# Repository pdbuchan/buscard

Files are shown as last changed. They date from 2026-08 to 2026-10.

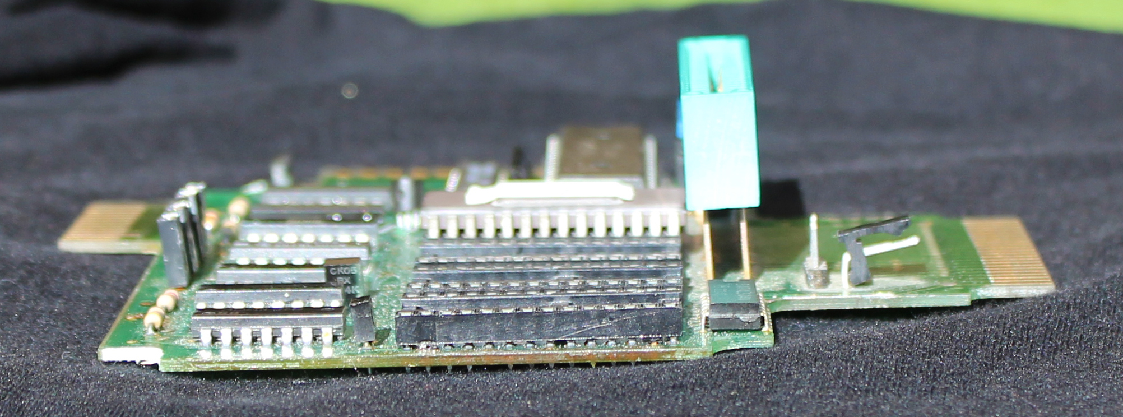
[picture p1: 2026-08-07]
docs/assets/images/side_view03.jpg

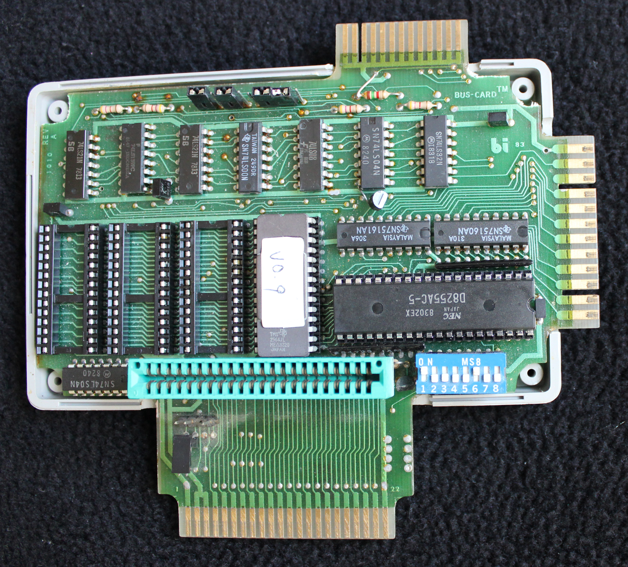
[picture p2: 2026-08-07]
docs/assets/images/top_with_bottom_cover1.jpg

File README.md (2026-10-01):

# BusCard Project

The illustrated project description is available on the [BusCard GitHub Pages website](https://pdbuchan.github.io/buscard/).

This repository documents information on the BusCard, an IEEE-488 and parallel printer interface for the Commodore 64. The BusCard, and subsequent BusCard II, were manufactured by Batteries Included Ltd. of Toronto, Canada. On my BusCard, the circuit board is labeled "Rev A" and "1983". I used it to provide IEEE-488 functionality to my Commodore 64 in order to use a 4040 disk drive and 8023P printer. It also provides BASIC 4.0 and comes with an assembler and disassembler.

Unlike the BusCard II, the BusCard does not contain any proprietary integrated circuits. As a result, I was able to successfully reverse-engineer it and produce an exact working duplicate. I used EAGLE CAD software for the schematic and circuit board design. All information required to produce it is provided. If you would like to build it, you can send the GERBER files provided here to the manufacturer of your choice. You would only need EAGLE if you wish to change the board layout or circuit.

## License

All of my photographs and EAGLE files are released under [Creative Commons License CC BY-SA](https://creativecommons.org/licenses/by-sa/4.0/). The original BusCard, EPROM content, and user manual are copyright Batteries Included Ltd.

## Repository layout

```text
buscard/
├── README.md
└── docs/
    ├── README.md
    ├── index.html
    ├── .nojekyll
    └── assets/
        ├── buscard.css
        ├── buscard_rev_a_manual.pdf
        ├── schematic.pdf
        ├── cam/
        │   ├── README.md
        │   └── elecrow-gerb274x.cam
        ├── datasheets/
        │   ├── README.md
        │   ├── datasheets.html
        │   ├── 1N4148.pdf
        │   ├── 2N3904.pdf
        │   ├── 2N4401.pdf
        │   ├── 74LS00N.pdf
        │   ├── 74LS04N.pdf
        │   ├── 74LS08N.pdf
        │   ├── 74LS139N.pdf
        │   ├── 74LS21N.pdf
        │   ├── 74LS32N.pdf
        │   ├── 75160B.pdf
        │   ├── 75161B.pdf
        │   ├── 8255AC-5.pdf
        │   ├── 82C55A.pdf
        │   ├── 8-SPST-DIP-Switch.pdf
        │   ├── CK05BX104K.pdf
        │   ├── clip_cable.pdf
        │   ├── clip_receptacle.pdf
        │   ├── female-edge-connector.pdf
        │   ├── micro_clip.pdf
        │   ├── resistor-network.pdf
        │   ├── resistors.pdf
        │   ├── shunt.pdf
        │   └── TMS2564.pdf
        ├── drawings/
        │   ├── README.md
        │   ├── buscard_dimensions.pdf
        │   ├── buscard_dimensions.vsdx
        │   ├── buscard_expansion_port.pdf
        │   ├── buscard_expansion_port.vsdx
        │   ├── buscard_IEEE-488_port.pdf
        │   ├── buscard_IEEE-488_port.vsdx
        │   ├── buscard_parallel_port.pdf
        │   ├── buscard_parallel_port.vsdx
        │   ├── buscard_parts_layout.pdf
        │   ├── buscard_parts_layout.vsdx
        │   ├── buscard_schematic.pdf
        │   ├── new_buscard_dimensions.pdf
        │   └── new_buscard_dimensions.vsdx
        ├── eagle/
        │   ├── README.md
        │   ├── buscard.brd
        │   └── buscard.sch
        ├── eprom/
        │   ├── README.md
        │   ├── buscardv0.9-tms2564.html
        │   ├── buscard_u1_rom_discussion.html
        │   ├── additional-sockets-u13-u14-u15.html
        │   ├── burning_TMS2564_EPROM.docx
        │   ├── burning_TMS2564_EPROM.pdf
        │   ├── buscard_u1_6502_annotated_listing.txt
        │   ├── buscard_u1_rom_discussion.md
        │   ├── additional-sockets-u13-u14-u15.md
        │   └── buscardv0.9-tms2564.bin
        ├── gerber/
        │   ├── README.md
        │   ├── gerber.html
        │   ├── buscard.GBL
        │   ├── buscard.GBO
        │   ├── buscard.GBS
        │   ├── buscard.GML
        │   ├── buscard.GTL
        │   ├── buscard.GTO
        │   ├── buscard.GTS
        │   ├── buscard.TXT
        │   ├── PLEASE_CHAMFER_CARD_EDGES.jpg
        │   └── PLEASE_CONTACT_ME_ABOUT_GOLD_FINGERS.txt
        ├── images/
        │   ├── README.md
        │   ├── orig_gallery.html
        │   ├── new_gallery.html
        │   ├── bottom_cover_inside.jpg
        │   ├── bottom_cover_inside_thumb.jpg
        │   ├── bottom_cover_underside.jpg
        │   ├── bottom_cover_underside_thumb.jpg
        │   ├── bottom.jpg
        │   ├── bottom_of_board_backlit.jpg
        │   ├── bottom_of_board_backlit_thumb.jpg
        │   ├── bottom_thumb.jpg
        │   ├── clips.jpg
        │   ├── clips_thumb.jpg
        │   ├── diodes.jpg
        │   ├── diodes-switch_foil_backlit_top.jpg
        │   ├── diodes-switch_foil_backlit_top_thumb.jpg
        │   ├── diodes-switch_foil_top.jpg
        │   ├── diodes-switch_foil_top_thumb.jpg
        │   ├── diodes_thumb.jpg
        │   ├── expansion_port_backlit1.jpg
        │   ├── expansion_port_backlit1_thumb.jpg
        │   ├── expansion_port_backlit2.jpg
        │   ├── expansion_port_backlit2_thumb.jpg
        │   ├── new_bottom.jpg
        │   ├── new_bottom_thumb.jpg
        │   ├── new_top1.jpg
        │   ├── new_top1_thumb.jpg
        │   ├── new_top2.jpg
        │   ├── new_top2_thumb.jpg
        │   ├── new_top_no_chips1.jpg
        │   ├── new_top_no_chips1_thumb.jpg
        │   ├── new_top_no_chips2.jpg
        │   ├── new_top_no_chips2_thumb.jpg
        │   ├── not_plugged_in.jpg
        │   ├── not_plugged_in_thumb.jpg
        │   ├── photo_buscard_board_bottom_r0.jpg
        │   ├── photo_buscard_board_top_r0.jpg
        │   ├── plugged_in.jpg
        │   ├── plugged_in_thumb.jpg
        │   ├── side_view01.jpg
        │   ├── side_view01_thumb.jpg
        │   ├── side_view02.jpg
        │   ├── side_view02_thumb.jpg
        │   ├── side_view03.jpg
        │   ├── side_view03_thumb.jpg
        │   ├── side_view04.jpg
        │   ├── side_view04_thumb.jpg
        │   ├── side_view05.jpg
        │   ├── side_view05_thumb.jpg
        │   ├── side_view06.jpg
        │   ├── side_view06_thumb.jpg
        │   ├── side_view07.jpg
        │   ├── side_view07_thumb.jpg
        │   ├── side_view08.jpg
        │   ├── side_view08_thumb.jpg
        │   ├── side_view09.jpg
        │   ├── side_view09_thumb.jpg
        │   ├── side_view10.jpg
        │   ├── side_view10_thumb.jpg
        │   ├── side_view11.jpg
        │   ├── side_view11_thumb.jpg
        │   ├── side_view12.jpg
        │   ├── side_view12_thumb.jpg
        │   ├── side_view13.jpg
        │   ├── side_view13_thumb.jpg
        │   ├── top_cover_inside.jpg
        │   ├── top_cover_inside_thumb.jpg
        │   ├── top_foil1.jpg
        │   ├── top_foil1_thumb.jpg
        │   ├── top_no_covers1.jpg
        │   ├── top_no_covers1_thumb.jpg
        │   ├── top_no_covers2.jpg
        │   ├── top_no_covers2_thumb.jpg
        │   ├── top_of_board_backlit.jpg
        │   ├── top_of_board_backlit_thumb.jpg
        │   ├── top_with_bottom_cover1.jpg
        │   ├── top_with_bottom_cover1_thumb.jpg
        │   ├── top_with_bottom_cover2.jpg
        │   ├── top_with_bottom_cover2_thumb.jpg
        │   ├── top_with_cover1.jpg
        │   ├── top_with_cover1_thumb.jpg
        │   ├── top_with_cover2.jpg
        │   └── top_with_cover2_thumb.jpg
        ├── libraries/
        │   ├── README.md
        │   ├── libraries.html
        │   ├── 1N4148.lbr
        │   ├── 2564.lbr
        │   ├── 2N3904_and_2N4401.lbr
        │   ├── 74LS00N.lbr
        │   ├── 74LS04N.lbr
        │   ├── 74LS08N.lbr
        │   ├── 74LS139N.lbr
        │   ├── 74LS21N.lbr
        │   ├── 74LS32N.lbr
        │   ├── 75160AN.lbr
        │   ├── 75161AN.lbr
        │   ├── 8255AC-5.lbr
        │   ├── capacitor-CK05BX104K.lbr
        │   ├── clip-header-MTA02-100.lbr
        │   ├── commodore-card-edges.lbr
        │   ├── dip-switch-DS08.lbr
        │   ├── female-44-pin-edge-connector.lbr
        │   ├── frame.lbr
        │   ├── jumper-header-3.lbr
        │   ├── mystery_plug-MTA04-100.lbr
        │   ├── resistor.lbr
        │   └── resistor-network-sil-G09R.lbr
        └── parts/
            ├── README.md
            ├── new_buscard_bom.xlsx
            └── orig_buscard_parts.xlsx
```

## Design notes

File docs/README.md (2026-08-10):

# Website HTML files and assets

This directory is the GitHub Pages document root.

| HTML File | Description |
|---|---|
| `index.html` | The project main webpage |
| `assets/images/orig_gallery.html` | A gallery webpage for the original BusCard |
| `assets/images/new_gallery.html` | A gallery webpage for my reverse-engineered BusCard |
| `assets/gerber/gerber.html` | A webpage for the GERBER files to be sent to a PCB manufacturer |
| `assets/datasheets/datasheets.html` | A webpage listing various component datasheets |
| `assets/libraries/libraries.html` | A webpage listing my custom EAGLE libraries for various components |
| `.nojekyll` | Tells GitHub Pages to serve the files without Jekyll processing |

| File | Description |
|---|---|
| `assets/buscard.css` | Shared stylesheet for BusCard project |
| `assets/buscard_rev_a_manual.pdf` | Scan of the BusCard manual with errata incorporated |
| `assets/schematic.pdf` | The reverse-engineered BusCard schematic, rendered by EAGLE |

| Directory | Description |
|---|---|
| `assets/cam/` | The EAGLE CAM file for generating the GERBER files |
| `assets/datasheets/` | Datasheets for the various BusCard components |
| `assets/drawings/` | My original hand-drawn schematic, and other drawings I prepared |
| `assets/eagle/` | EAGLE board and schematic files |
| `assets/eprom/` | TMS-2564 EPROM binary image, as well as instructions for burning copies using the Promenade EPROM burner |
| `assets/gerber/` | The GERBER files to be sent to a PCB manufacturer |
| `assets/images/` | Photographs of the original and reverse-engineered BusCards |
| `assets/libraries/` | My custom EAGLE libraries for various components |
| `assets/parts/` | Parts lists for original and new BusCards as Microsoft Excel spreadsheets |

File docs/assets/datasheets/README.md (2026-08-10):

# Datasheets for various components of the BusCard

| File | Description |
|---|---|
| `1N4148.pdf` | Small Signal Diode, 200 mA, 100 V |
| `2N3904.pdf` | NPN Transistor, 200 mA, 40 V |
| `2N4401.pdf` | NPN Transistor, 600 mA, 40 V |
| `74LS00N.pdf` | Quadruple 2-Input Positive-NAND Gates |
| `74LS04N.pdf` | Hex Inverting Gates |
| `74LS08N.pdf` | Quadruple 2-Input Positive-AND Gates |
| `74LS139N.pdf` | Dual 1-of-4 Decoder/Demultiplexer |
| `74LS21N.pdf` | Dual 4-Input Positive-AND Gates |
| `74LS32N.pdf` | Quadruple 2-Input Positive-OR Gates |
| `75160B.pdf` | IEEE-488 GPIB Octal Bus Transceiver |
| `75161B.pdf` | IEEE-488 GPIB Octal Bus-Management and Data-Transfer Transceiver |
| `8255AC-5.pdf` | Programmable Peripheral Interface, 40-Pin, 4 MHz |
| `82C55A.pdf` | Programmable Peripheral Interface, 40-Pin, 4 MHz |
| `8-SPST-DIP-Switch.pdf` | 8 SPST DIP Switch, Raised Slide |
| `CK05BX104K.pdf` | Ceramic Capacitor, 0.1 uF, 50 V, Radial, 10% tolerance |
| `clip_cable.pdf` | Ribbon cable |
| `clip_receptacle.pdf` | Receptacle for ribbon cable |
| `female-edge-connector.pdf` | Edge connector for accepting Commodore cartridges |
| `micro_clip.pdf` | Micro clip for ribbon cable |
| `resistor-network.pdf` | SIL Resistor Network, 4.67 kohm, 10 Pins, 9 Resistors, Bussed Arrangement |
| `resistors.pdf` | Resistor (general) |
| `shunt.pdf` | Shunts for jumpering pins on BusCard |
| `TMS2564.pdf` | 65,536-bit, Ultraviolet-Erasable, Electrically Programmable Read-Only Memory (EPROM) |

## File for GitHub Pages
| File | Description |
|---|---|
| `datasheets.html` | Webpage about datasheets for GitHub Pages |

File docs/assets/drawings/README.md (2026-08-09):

# My original hand-drawn schematic, and other drawings I produced

| File | Description |
|---|---|
| `buscard_dimensions.pdf` | Original BusCard printed circuit board dimensions as PDF |
| `buscard_dimensions.vsdx` | Original BusCard printed circuit board dimensions as Microsoft Visio drawing |
| `buscard_expansion_port.pdf` | BusCard expansion port dimensions as PDF |
| `buscard_expansion_port.vsdx` | BusCard expansion port dimensions as Microsoft Visio drawing |
| `buscard_IEEE-488_port.pdf` | IEEE-488 port pinout as PDF |
| `buscard_IEEE-488_port.vsdx` | IEEE-488 port pinout as Microsoft Visio drawing |
| `buscard_parallel_port.pdf` | BusCard parallel port pinout as PDF |
| `buscard_parallel_port.vsdx` | BusCard parallel port pinout as Microsoft Visio drawing |
| `buscard_parts_layout.pdf` | BusCard parts layout as PDF, referencing component IDs in `assets/parts/orig_buscard_parts.xlsx` |
| `buscard_parts_layout.vsdx` | BusCard parts layout referencing component IDs in `assets/parts/buscard_bom.xlsx and buscard_parts_list.txt` as Microsoft Visio drawing |
| `buscard_schematic.pdf` | My original hand-drawn schematic |
| `new_buscard_dimensions.pdf` | Reverse-engineered BusCard printed circuit board dimensions as PDF |
| `new_buscard_dimensions.vsdx` | Reverse-engineered BusCard printed circuit board dimensions as Microsoft Visio drawing |

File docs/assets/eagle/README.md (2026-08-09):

# EAGLE board and schematic files

| File | Description |
|---|---|
| `buscard.brd` | EAGLE printed circuit board file |
| `buscard.sch` | EAGLE schematic file |

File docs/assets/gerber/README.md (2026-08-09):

# GERBER files to send to PCB manufacturer

| File | Description |
|---|---|
| `buscard.GBL` | Bottom copper layer |
| `buscard.GBO` | Bottom overlay (silkscreen) |
| `buscard.GBS` | Bottom solder mask |
| `buscard.GML` | Mill layer |
| `buscard.GTL` | Top copper layer |
| `buscard.GTO` | Top overlay (silkscreen) |
| `buscard.GTS` | Top solder mask |
| `buscard.TXT` | Drill file |

At the time I had my boards manufactured, [Elecrow](https://www.elecrow.com/) told me to include a request for them to contact me regarding gold fingers.

| File | Description |
|---|---|
| `PLEASE_CHAMFER_CARD_EDGES.jpg` | Shows locations of PCB edges to be chamfered. |
| `PLEASE_CONTACT_ME_ABOUT_GOLD_FINGERS.txt` | Instruction to contact me regarding gold fingers. |

## File for GitHub Pages

| File | Description |
|---|---|
| `gerber.html` | HTML webpage for GitHub Pages regarding GERBER files |

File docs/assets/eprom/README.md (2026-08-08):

# BusCard (Revision A) TMS-2564 EPROM v0.9 (U1)

| File | Description |
|---|---|
| `buscardv0.9-tms2564.bin` | Binary image of BusCard EPROM |
| [`buscard_u1_rom_discussion.md`](buscard_u1_rom_discussion.md) | Discussion of BusCard TMP-2564 EPROM U1 Disassembly |
| `buscard_u1_6502_annotated_listing.txt` | BusCard TMP-2564 EPROM U1 Annotated Disassembly |
| [`additional-sockets-u13-u14-u15.md`](additional-sockets-u13-u14-u15.md) | Discussion on the U13, U14, and U15 EPROM Sockets |

## Instructions for Burning Copies of the EPROM

| File | Description |
|---|---|
| `burning_TMS2564_EPROM.docx` | Instructions for burning copies of the BusCard EPROM using the Promenade EPROM burner as Microsoft Word document |
| `burning_TMS2564_EPROM.pdf` | Instructions for burning copies of the BusCard EPROM using the Promenade EPROM burner as PDF |

## Files for GitHub Pages

| File | Description |
|---|---|
| `buscardv0.9-tms2564.html` | Webpage for BusCard TMP-2564 EPROM U1 |
| `buscard_u1_rom_discussion.html` | Discussion of BusCard TMP-2564 EPROM U1 Disassembly |
| `additional-sockets-u13-u14-u15.html` | Discussion on the U13, U14, and U15 EPROM Sockets |

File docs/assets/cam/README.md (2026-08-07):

# EAGLE CAM file for generating the GERBER files to be sent to manufacturer

I hired [Elecrow](https://www.elecrow.com/) to manufacture my boards.

`elecrow-gerb274x.cam`

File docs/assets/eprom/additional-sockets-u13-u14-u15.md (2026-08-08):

# Batteries Included BusCard U13, U14, and U15 EPROM Sockets
## Purpose and relationship to the U1 firmware

## Purpose of this document

The Batteries Included BusCard contains one normally populated TMS2564 EPROM,
U1, and three additional TMS2564 sockets, XU13, XU14, and XU15. On the BusCard
examined during this project, only U1 was populated. The purpose of the three
additional sockets is therefore not immediately obvious from the surviving
board alone.

Reverse engineering of U1, examination of the BusCard schematic, and comparison
with the current MAME BusCard hardware model now allow the hardware role of
U13-U15 to be described with fairly high confidence. Their **exact original ROM
contents remain unknown**, but their electrical function and likely intended
software role are much clearer.

The principal conclusion is:

> **U13, U14, and U15 form an optional three-bank ROM facility that can replace
> the normal C64 BASIC ROM in the `$A000-$BFFF` address range. Together they
> provide 24K of physical ROM storage, but only one 8K bank is visible to the
> 6510 at a time. The available evidence strongly indicates that this facility
> was intended for an optional BASIC-related ROM package, distinct from the
> smaller BASIC 4.0-style command extension already contained in U1.**

This distinction between the U1 command extension and the optional U13-U15 ROM
facility is important.

## What the U1 disassembly established

U1 is an 8192-byte TMS2564 EPROM, but it is not used as one simple contiguous
8K program. The BusCard maps different parts of U1 into different parts of the
C64 address space. The reconstructed organization is:

| Physical U1 offset | CPU address | Principal contents |
| --- | --- | --- |
| `$0000-$0BFF` | `$A000-$ABFF` | Machine-language monitor and low-level BusCard I/O drivers |
| `$0C00-$0FFF` | `$EC00-$EFFF` | Resident C64 KERNAL overlay and BusCard dispatch code |
| `$1000-$113B` | `$B000-$B13B` | BASIC extension installer/uninstaller and associated data |
| `$113C-$147A` | `$B13C-$B47A` | Zero fill |
| `$147B-$1FFF` | `$B47B-$BFFF` | Encoded relocatable BASIC command extension |

The resident ROM provides three public entry points:

| BASIC command | Address | Function |
| --- | ---: | --- |
| `SYS 61000` | `$EE48` | Install/enable the BusCard BASIC 4.0-style command extension |
| `SYS 61003` | `$EE4B` | Remove/disable the command extension |
| `SYS 61006` | `$EE4E` | Enter the BusCard machine-language monitor |

The important discovery is that `SYS 61000` does **not** enable U13, U14, or
U15. Instead, U1 contains an encoded relocation stream. The installer expands
this code into RAM below BASIC's current `MEMSIZ`, then hooks four standard
BASIC indirect vectors. On a stock C64 with `MEMSIZ=$A000`, the reconstructed
runtime extension occupies `$955B-$9FFF` and is 2725 bytes long.

The relocated image identifies itself as `BASIC 4.0` and adds fifteen
Commodore-style disk commands:

```
CONCAT   DOPEN    DCLOSE   RECORD    HEADER
COLLECT  BACKUP   COPY     APPEND    DSAVE
DLOAD    CATALOG  RENAME   SCRATCH   DIRECTORY
```

This means that the BusCard already supplies a useful BASIC 4.0-style disk
command environment using **U1 alone**. The optional sockets are therefore not
required merely to make `SYS 61000` work, and they would not simply contain
three more pieces of the U1 command wedge.

## What the schematic says about U13-U15

The schematic shows four TMS2564 devices associated with the BusCard ROM
system:

- U1, controlled by `PD/!PGM1`;
- U13, controlled by `PD/!PGM2`;
- U14, controlled by `PD/!PGM3`;
- U15, controlled by `PD/!PGM4`.

U13, U14, and U15 share the same address and data buses. Each is an 8K x 8
EPROM, so the three sockets provide 24K of physical storage.

The crucial difference is their chip-selection logic. Two outputs from the
Intel 8255 PPI, `PB0` and `PB1`, feed one half of U10, a 74LS139 two-to-four
line decoder. Three decoder outputs are wired to the three optional EPROMs:

| 8255 bank bits | 74LS139 output | Selected EPROM |
| --- | --- | --- |
| `PB1 PB0 = 00` | `Y0` / `PD/!PGM4` | U15 |
| `PB1 PB0 = 01` | `Y1` / `PD/!PGM3` | U14 |
| `PB1 PB0 = 10` | `Y2` / `PD/!PGM2` | U13 |
| `PB1 PB0 = 11` | `Y3` | No U13-U15 EPROM is connected to this decoder output |

Thus U13-U15 are **banks**, not three simultaneously visible 8K pieces of a
24K linear address range.

A third 8255 signal, `PB3`, controls whether this optional ROM bank system is
enabled. MAME's BusCard implementation describes the PPI Port B bits as:

```
PB0  BASIC ROM bank bit 0
PB1  BASIC ROM bank bit 1
PB3  BASIC ROM enable
PB6  printer STROBE
PB7  DIP-switch select
```

Those names are consistent with both the schematic and the behavior recovered
from U1.

## The `$A000-$BFFF` BASIC-ROM window

The most revealing point is where the optional ROMs appear in the C64 memory
map. MAME models U13-U15 as mutually exclusive 8K images at the same CPU
address range:

```
$A000-$BFFF
```

That is the normal C64 BASIC ROM window.

The same address window is also used temporarily by U1. When BusCard firmware
needs its monitor, I/O drivers, or BASIC-extension installer, the hardware can
map U1 over `$A000-$BFFF`. When that operation finishes, the normal memory map
is restored.

The resulting arrangement can be summarized as follows:

| BusCard ROM state | `$A000-$BFFF` contents |
| --- | --- |
| BusCard firmware selected (`PB3=0` in the MAME model) | U1 |
| Optional BASIC-ROM mode, bank `10` | U13 |
| Optional BASIC-ROM mode, bank `01` | U14 |
| Optional BASIC-ROM mode, bank `00` | U15 |
| Optional BASIC-ROM mode, bank `11` | No optional EPROM selected; normal C64 BASIC can remain visible |

The precise logic also depends on the normal C64 `LORAM`/`HIRAM` memory-control
conditions. The table is intended to show the BusCard's ROM-selection concept,
not replace the complete C64 PLA/memory-map truth table.

This organization explains why four physical 8K EPROM positions can coexist
without requiring a 32K continuous cartridge address space: they are selected
at different times and share the same 8K CPU window.

## Why the unused `11` bank state matters

U10 is a two-to-four decoder, so `PB0` and `PB1` naturally provide four bank
states. Only three outputs are connected to U13-U15. The fourth state is not
used for another optional EPROM.

This is not an accidental curiosity. U1's normal PPI initialization uses a
Port B state whose low two bits are both set, while the BASIC-ROM-enable state
is also set. MAME likewise initializes the emulated card with bank value 3.
In that state none of the three optional ROMs is selected, allowing the stock
C64 BASIC ROM to remain available.

The four possible low-bit states therefore make good architectural sense:
three optional ROM banks plus a fourth selection that does not substitute an
optional ROM.

## Relationship to U1's BASIC 4.0-style extension

The most tempting interpretation of U13-U15 is that they must contain the
`BASIC 4.0` code mentioned by the BusCard manual and by `SYS 61000`. The U1
disassembly shows that this cannot be the whole story.

The standard U1 firmware already contains the code that `SYS 61000` installs.
That package is small enough to be encoded in the tail of U1 and relocated into
RAM. It extends the existing C64 BASIC 2.0 environment through the standard
BASIC vectors; it does not replace the entire BASIC ROM.

U13-U15, by contrast, are a hardware ROM-banking system capable of substituting
one of three 8K EPROMs directly into the C64 BASIC ROM address space. This is a
fundamentally different mechanism.

The evidence therefore points to two separate facilities:

1. **U1 BASIC 4.0-style command extension** -- a compact disk-command package
   stored in U1, expanded into RAM, and enabled by `SYS 61000`.
2. **U13-U15 optional BASIC-ROM facility** -- up to 24K of additional physical
   ROM, bank-selected into `$A000-$BFFF` by the 8255 and external decode logic.

They could coexist because the BusCard's resident `$EC00-$EFFF` KERNAL overlay
remains available independently of which program ROM is selected in the BASIC
window. An optional BASIC environment in U13-U15 could therefore still make
use of the BusCard's KERNAL interception and IEEE-488/parallel-printer support.

## What was U13-U15 most likely intended to contain?

The hardware evidence supports a **BASIC-related purpose** strongly:

- `PB0` and `PB1` are the ROM-bank select bits;
- `PB3` is explicitly identified in the MAME hardware model as `BASIC ROM
  enable`;
- the selected EPROM replaces the C64 BASIC ROM at `$A000-$BFFF`;
- the BusCard was advertised/documented as providing BASIC 4.0 functionality;
- three 8K devices provide enough storage for a substantially larger ROM-based
  language environment than the 2725-byte U1 command extension.

For these reasons, the most plausible interpretation is that Batteries
Included designed XU13-XU15 for an **optional banked BASIC ROM package**, very
possibly a more extensive BASIC 4.0 environment than the small disk-command
extension built into U1.

There are two closely related ways the sockets could have been used:

- as three banks belonging to one larger, bank-switched software package; or
- as up to three separately selectable 8K ROM images associated with the
  optional BASIC-ROM feature.

The circuit alone does not distinguish these possibilities. What it proves is
the banking mechanism and address window, not the software organization inside
missing EPROMs.

## What we should not claim

At present there are no known U13, U14, or U15 ROM dumps in the material used
for this reverse engineering. MAME deliberately declares the three images as
`unpopulated.u13`, `unpopulated.u14`, and `unpopulated.u15`, while the known U1
image is loaded normally as `0.9.u1`.

Consequently, the evidence does **not** establish any of the following:

- that U13-U15 were populated on every BusCard;
- that Batteries Included necessarily shipped a three-ROM set with the card;
- that the three ROMs contained an unmodified Commodore PET/CBM BASIC 4.0 ROM
  set;
- that all 24K formed one continuous logical program;
- the exact entry points, commands, bank-switching protocol, or revision of
  any software intended for those sockets.

In particular, it would be premature to identify the missing ROMs with a
specific Commodore BASIC 4.0 ROM set merely because the BusCard uses the phrase
`BASIC 4.0`. The U1 firmware demonstrates that Batteries Included already used
that term for its own compact C64 extension.

## Confidence of the present conclusions

| Conclusion | Confidence | Basis |
| --- | --- | --- |
| U13-U15 are three 8K TMS2564 ROM positions | Very high | Schematic and device type |
| They share the `$A000-$BFFF` CPU window rather than forming a directly visible 24K range | Very high | Decode logic and MAME hardware model |
| `PB0/PB1` select among U15, U14, and U13 | Very high | Schematic 74LS139 wiring and MAME bank mapping |
| `PB3` enables the optional BASIC-ROM selection mechanism | Very high | MAME PPI description and ROM decode behavior |
| The fourth bank code (`11`) leaves no U13-U15 EPROM selected | High | Unused decoder output plus MAME behavior |
| U13-U15 are separate from the U1 `SYS 61000` RAM-resident command extension | Very high | U1 disassembly and relocation analysis |
| The sockets were intended for a larger optional BASIC-related ROM facility | High, but inferential | Address window, control-signal role, capacity, and BusCard feature set |
| They contained an exact Commodore PET/CBM BASIC 4.0 ROM set | Unknown | No ROM dumps or definitive documentation presently available |

## What would settle the remaining questions

The most valuable discovery would be an original BusCard with one or more of
XU13-XU15 populated. Even photographs of EPROM labels could identify a product
or revision. Ideally the chips could be dumped and compared with known
Commodore and Batteries Included ROMs.

Other useful evidence would include:

1. an original option sheet, price list, dealer catalog, or advertisement that
   specifically mentions the three-ROM option;
2. a BusCard manual revision describing XU13-XU15 or ROM bank selection;
3. surviving EPROM images labelled U13, U14, or U15;
4. another BusCard firmware revision that contains code explicitly selecting
   banks 0, 1, or 2 for an optional language package;
5. execution traces from a populated board or a reconstructed ROM set in MAME.

Until such evidence is found, the best description is functional rather than
historical: **XU13-XU15 are sockets for three optional, bank-selected 8K ROMs in
the C64 BASIC address space, with strong evidence that the facility was
intended for BASIC-related expansion.**

## References

- BusCard project repository: <https://github.com/pdbuchan/buscard>
- Reverse-engineered EAGLE schematic: <https://github.com/pdbuchan/buscard/blob/main/docs/assets/eagle/buscard.sch>
- BusCard schematic PDF: <https://github.com/pdbuchan/buscard/blob/main/docs/assets/schematic.pdf>
- Original BusCard Rev A manual: <https://github.com/pdbuchan/buscard/blob/main/docs/assets/buscard_rev_a_manual.pdf>
- MAME BusCard implementation: <https://github.com/mamedev/mame/blob/master/src/devices/bus/c64/buscard.cpp>
- Companion U1 annotated 6502 disassembly: `buscard_u1_6502_annotated_listing.txt`
- Companion U1 ROM discussion: `buscard_u1_rom_discussion.md`

## Summary

U13, U14, and U15 are best understood not as missing pieces required by the
standard U1 firmware, but as an **optional banked ROM expansion subsystem**.
Each socket accepts an 8K TMS2564, and the three devices share the C64
`$A000-$BFFF` BASIC-ROM window. The 8255's `PB0` and `PB1` outputs select one of
the three EPROMs through a 74LS139 decoder, while `PB3` controls the BASIC-ROM
selection mode.

U1 itself already supplies the BusCard's monitor, low-level I/O support,
KERNAL interception, and a compact BASIC 4.0-style command package that is
relocated into RAM. U13-U15 therefore represent a second and more expansive
ROM facility. The strongest interpretation is that they were intended for an
optional banked BASIC environment, but without surviving ROM dumps or explicit
documentation the exact software that Batteries Included intended to place in
those sockets remains an open question.

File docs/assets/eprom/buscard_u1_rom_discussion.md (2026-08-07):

# Batteries Included BusCard U1 ROM
## General Discussion and Reverse-Engineering Notes

### Purpose of this document

This document accompanies the annotated 6502 assembler listing of the
Batteries Included BusCard U1 EPROM image, `buscardv0.9-tms2564.bin`.

The listing is a reverse-engineered description of the ROM rather than the
original Batteries Included source code. Symbol names, routine names, and
comments were reconstructed from the machine code, the BusCard schematic,
known Commodore 64 memory and KERNAL conventions, the BusCard implementation
in MAME, and comparison with published Commodore ROM disassemblies. Where the
function of a routine is not yet certain, the annotated listing deliberately
uses a neutral name rather than assigning a possibly incorrect historical
name.

The purpose of this discussion is to describe the overall architecture of the
firmware and explain how its major parts fit together. It is intended to be
read before, or alongside, the detailed assembler listing.

## ROM identity

The U1 image is 8192 bytes long, corresponding exactly to one TMS2564 8K x 8
EPROM. Its checksums are:

```
CRC32:   175e8c96
SHA-1:   8fb4ba7e3d0b58dc01b66ef962955596f1b125b5
SHA-256: c96f1b19aacd3f05fcd539c76dd476613d680c0ef03d7c26725a7e40a99e851a
```

The CRC32 and SHA-1 values match the BusCard U1 ROM identified by MAME as
`0.9.u1`. This provides useful independent confirmation that the image being
disassembled is a known BusCard firmware revision rather than an altered or
partially damaged dump.

## U1 is not a simple contiguous 8K program

The most important fact to understand when reading the listing is that U1 is
not used as one uninterrupted program occupying a single 8K address range.
The BusCard's address-decoding circuitry exposes different portions of the
physical EPROM at different locations in the Commodore 64 address space.

The organization recovered from the ROM and hardware is:

| Physical U1 offset | CPU address | Principal contents |
| --- | --- | --- |
| `$0000-$0BFF` | `$A000-$ABFF` | Machine-language monitor and BusCard low-level I/O drivers |
| `$0C00-$0FFF` | `$EC00-$EFFF` | Resident C64 KERNAL overlay and BusCard dispatch code |
| `$1000-$113B` | `$B000-$B13B` | BASIC 4.0 extension installer/uninstaller and associated data |
| `$113C-$147A` | `$B13C-$B47A` | 831 bytes of zero fill |
| `$147B-$1FFF` | `$B47B-$BFFF` | Encoded relocatable BASIC 4.0 command extension |

This mapping is why a conventional disassembly that simply assumes the whole
8K ROM occupies `$A000-$BFFF` gives misleading addresses for a significant
portion of the firmware. In particular, physical offsets `$0C00-$0FFF` are
intended to appear at `$EC00-$EFFF`, where they replace part of the normal C64
KERNAL address space.

The annotated listing therefore shows both the physical EPROM offset and the
CPU address at which each byte is intended to execute.

## Public entry points

Three consecutive public entry points are present in the resident ROM area:

| BASIC command | Address | Function |
| --- | ---: | --- |
| `SYS 61000` | `$EE48` | Install/enable the BusCard BASIC 4.0 command extension |
| `SYS 61003` | `$EE4B` | Remove/disable the BASIC 4.0 command extension |
| `SYS 61006` | `$EE4E` | Enter the BusCard machine-language monitor |

These are implemented as three-byte JMP instructions, which explains why the
entry points are spaced three bytes apart.

The three entry points also provide a useful high-level description of the
U1 firmware. U1 is not merely an IEEE-488 driver ROM. It contains three major
software facilities:

1. low-level BusCard I/O support and C64 KERNAL interception;
2. a machine-language monitor/assembler/disassembler; and
3. a relocatable BASIC command extension providing BASIC 4.0-style disk
   commands.

## Machine-language monitor

The first major component of U1 is a substantial machine-language monitor at
approximately `$A000-$A7D2`.

`SYS 61006` does not simply jump directly into the monitor. The firmware first
installs `$ED8B` in the C64 BRK vector at `$0316/$0317`, enables KERNAL
messages, and deliberately executes a `BRK` instruction. The BusCard BRK
handler then maps the appropriate U1 ROM region and transfers control to
`$A000`.

This mechanism allows the monitor to enter with a normal 6502 BRK stack frame.
The monitor removes that frame and records the interrupted processor state,
including:

- program counter;
- processor status register;
- accumulator;
- X register;
- Y register; and
- stack pointer.

The saved program counter is adjusted by two bytes so that it identifies the
actual `BRK` instruction rather than the address following it.

The reconstructed monitor command table contains the following commands:

| Command | Function |
| --- | --- |
| `R` | Display/edit saved registers |
| `M` | Display or modify memory |
| `G` | Go/execute from a specified address |
| `X` | Exit the monitor |
| `L` | Load memory from a device/file |
| `S` | Save memory to a device/file |
| `T` | Transfer a block of memory |
| `F` | Fill memory |
| `H` | Hunt/search memory |
| `D` | Disassemble machine code |
| `P` | Print disassembly |
| `A` | Assemble a line of 6502 code |
| `:` | Memory-edit line |
| `;` | Display/edit helper |
| `,` | Assembly/edit continuation helper |

The monitor is therefore much more than a simple memory viewer. It contains a
6502 disassembler and assembler as well as the usual memory manipulation,
execution, load/save, and register facilities expected of a serious
machine-language monitor of the period.

## The resident KERNAL overlay

A particularly interesting feature of the BusCard design is the use of U1 as
a partial replacement for the C64 KERNAL in the `$EC00-$EFFF` region.

Large portions of the beginning of this ROM section are deliberately identical
or very close to the stock Commodore KERNAL. They include keyboard/editor
data, VIC-II defaults, the `LOAD` and `RUN` text, and screen-line tables. This
is necessary because when the BusCard hardware overlays this address range,
ordinary KERNAL data that normally occupies the same addresses must remain
available.

The important changes begin in the KERNAL serial-device routines. At `$ED09`
the normal TALK/LISTEN code begins in the expected manner, but at `$ED0E` the
BusCard replaces the normal continuation with:

```
JMP $ED23
```

This transfers control to BusCard-specific dispatch logic rather than allowing
the stock Commodore serial-bus routine to continue unchanged.

The result is a relatively elegant interception scheme. Programs can continue
to use the standard C64 KERNAL I/O entry points, while the BusCard decides
whether a particular request should be handled by its IEEE-488 interface, its
parallel-printer interface, or an appropriate compatible C64 serial path.

This also explains why the firmware contains a mixture of code that is
byte-for-byte Commodore KERNAL material, lightly modified KERNAL entry paths,
and wholly new BusCard code.

## Intel 8255 PPI and the BusCard hardware

The BusCard uses an Intel 8255 programmable peripheral interface at
`$DEC0-$DEC3`. The firmware accesses these registers repeatedly in the
low-level I/O section.

The recovered functions of the ports are:

| Address | 8255 register | BusCard use |
| --- | --- | --- |
| `$DEC0` | Port A | IEEE-488 DIO0-DIO7; also Centronics printer D0-D7; DIP-switch input when selected |
| `$DEC1` | Port B | ROM-bank control, BASIC-ROM enable, printer STROBE, and DIP-switch selection |
| `$DEC2` | Port C | IEEE-488 handshake/control signals and printer BUSY |
| `$DEC3` | Control register | 8255 mode control and bit set/reset operations |

Port A is consequently shared between two principal external data paths: the
8-bit IEEE-488 data bus and the 8-bit parallel-printer data bus. Port C carries
much of the associated handshaking, while Port B performs several control
functions that include ROM selection as well as printer and switch control.

The low-level code beginning near `$A7D3` contains the detailed handshake and
routing machinery. The annotated listing identifies accesses to the 8255 and
many higher-level relationships, but some of the smallest helper routines
retain neutral names such as `BUSCARD_IO_ROUTINE_A80A`. The exact semantic
role of every individual handshake helper has not yet been proven closely
enough to justify assigning all of them historical-sounding names.

## IEEE-488, printer, and normal C64 device routing

The firmware is structured so that applications continue to use familiar C64
KERNAL device operations. The BusCard intercepts selected KERNAL paths and
examines the current device/interface configuration before routing the
operation.

This is an important architectural point. The BusCard does not require every
application to know how to manipulate the IEEE-488 bus directly. Instead, it
inserts itself beneath the normal C64 I/O conventions and provides alternate
hardware implementations of those operations.

This arrangement is appropriate for the BusCard's intended use with IEEE-488
Commodore peripherals, such as the 4040 dual disk drive, while retaining
support for a parallel printer and ordinary C64 device behavior where
appropriate.

The firmware also saves and restores C64 memory-configuration and BusCard
control state around many of these operations. Routines such as
`MAP_BUSCARD_ROM` and `RESTORE_MEMORY_MAPPING` are therefore central to the
implementation: BusCard ROM must be visible while its own code executes, but
the machine must subsequently be returned to the expected C64 memory map.

## BASIC 4.0-style command extension in U1

U1 contains a BASIC extension that adds a collection of disk-oriented commands
to the standard C64 BASIC environment. This is the facility installed by
`SYS 61000` and removed by `SYS 61003`.

The terminology deserves some care. The U1 ROM undeniably identifies the
resident extension with the string `BASIC 4.0`, and it supplies a set of
BASIC 4.0-style disk commands. This small extension should not automatically
be equated with the optional 24K of ROM associated with sockets XU13-XU15.
The U1 extension is a compact command package that relocates into RAM; the
three additional 8K EPROM sockets constitute a separate, much larger optional
ROM facility.

### Why the extension is stored in encoded form

The tail of U1, physical offsets `$147B-$1FFF`, cannot be sensibly
interpreted as ordinary 6502 instructions in place. It is an encoded
relocation stream.

When the extension is installed, the routine at `$B03C` starts just beyond the
end of the encoded data and walks backward through the source. At the same
time it walks the C64 BASIC `MEMSIZ` pointer downward, constructing the runtime
extension immediately below the current top of BASIC memory.

Most encoded bytes are copied literally. A zero byte introduces special
handling: an escaped zero represents a literal zero, while another form
contains a 16-bit relocatable address offset. The installer adds the original
`MEMSIZ` value to these offsets before storing the resulting absolute address.
This allows the package to execute correctly even when the top of BASIC memory
is not fixed at one particular address.

The installer also checks the BASIC variable boundary while copying. If the
new code would collide with existing BASIC variables, the installation is
aborted and the original memory pointers are restored.

### Runtime location on a stock C64

For a normal C64 with BASIC `MEMSIZ=$A000`, decoding the stream with the ROM's
own relocation rules produces a 2725-byte runtime image occupying:

```
$955B-$9FFF
```

The encoded stream contains 154 relocation records. The annotated assembler
listing includes a separate *derived* disassembly of this runtime image.
Those derived lines do not represent additional bytes in U1; they show what
the encoded bytes become after the installer has expanded and relocated them
in RAM.

### BASIC vector interception

After relocation, the installer changes four standard BASIC indirect vectors
at `$0304-$030B`:

- ICRNCH -- BASIC tokenizer/crunch hook;
- IQPLOP -- BASIC LIST/detokenizer hook;
- IGONE -- BASIC statement-dispatch hook; and
- IEVAL -- BASIC expression-evaluation hook.

The first twelve bytes of the relocated block are four three-byte JMP
instructions, one for each of these hooks. Immediately following them is the
NUL-terminated signature:

```
BASIC 4.0
```

Through these four vectors, the BusCard can extend BASIC without replacing the
entire C64 BASIC ROM. Normal BASIC syntax and execution continue through the
stock ROM when the BusCard extension has nothing special to handle.

### Additional BASIC keywords

The decoded runtime image contains a Commodore-style keyword table. The high
bit of the last character of each keyword marks the end of the keyword, in the
same general style used by Commodore BASIC ROMs.

Fifteen additional commands are present:

```
CONCAT
DOPEN
DCLOSE
RECORD
HEADER
COLLECT
BACKUP
COPY
APPEND
DSAVE
DLOAD
CATALOG
RENAME
SCRATCH
DIRECTORY
```

The extension tokenizer recognizes these commands and assigns them additional
BASIC token values beginning at `$CC`. The LIST hook performs the reverse
operation, translating those tokens back into their textual keyword names
when a BASIC program is listed.

A handler table then dispatches the tokens to the appropriate routines. Of
particular interest, `CATALOG` and `DIRECTORY` share the same handler, making
them alternate names for the same operation.

Several handlers ultimately use ordinary C64 KERNAL file operations after
constructing the required disk command or filename syntax. This reinforces
the overall BusCard design philosophy: extend the standard C64 software
interfaces and route their actual I/O through the BusCard hardware rather than
creating an entirely separate programming environment.

### Removing the extension

`SYS 61003` restores the four standard C64 BASIC vectors. The uninstaller also
checks for the `BASIC 4.0` signature in the relocated RAM image, restores the
saved pre-installation `MEMSIZ`, and synchronizes BASIC's related memory
pointers.

Thus installation is not simply a matter of turning on a hardware ROM bank.
For the U1 command extension, code is actually expanded into RAM and BASIC's
memory boundary is lowered to reserve space for it.

## Relationship to the optional U13, U14, and U15 EPROMs

The U1 disassembly helps clarify an apparent ambiguity in the BusCard
architecture.

The standard U1 firmware already provides BASIC 4.0-style disk commands. That
is the compact relocatable extension described above. The schematic, however,
contains sockets XU13, XU14, and XU15 for three additional TMS2564 EPROMs,
totaling 24K. Their selection is controlled by BusCard hardware and by 8255
Port B bank-control bits.

The existence of the U1 extension therefore does **not** mean that U13-U15
would merely duplicate the same code. The evidence instead points to two
distinct facilities:

- U1 supplies the standard BusCard firmware, monitor, device drivers, KERNAL
  patches, and a relatively small RAM-resident set of BASIC 4.0-style disk
  commands.
- U13-U15 provide the hardware capacity for a separate optional 24K ROM BASIC
  4.0 facility.

Precisely what software was supplied in the optional three-ROM set cannot be
determined from the U1 image alone. Until original U13-U15 dumps or their
specific documentation are located, it is preferable not to claim that they
contain an exact copy of any particular Commodore PET/CBM BASIC ROM set.

## Some notable implementation techniques

Several techniques in U1 are representative of carefully written 6502
firmware of its period.

### Computed dispatch with RTS

Both the monitor and BASIC extension use tables containing handler addresses
stored as `address - 1`. The low and high bytes are pushed on the stack and an
`RTS` instruction is executed. Because `RTS` increments the pulled address by
one, control arrives at the desired handler. This provides a compact computed
subroutine-dispatch mechanism on a processor without an indirect JSR
instruction.

### Partial ROM overlay rather than wholesale replacement

The `$EC00-$EFFF` region preserves the stock bytes that must remain visible and
changes only the portions necessary for BusCard interception. This reduces the
amount of Commodore behavior that the board needs to reimplement.

### Relocatable RAM extension

The BASIC command package is not tied to one absolute RAM address. Encoding
absolute references as offsets from the original BASIC `MEMSIZ` permits the
installer to place it immediately below the current top of BASIC memory. For a
stock C64 that is `$955B-$9FFF`, but the design itself is more general.

### Integration through standard vectors

Rather than replacing BASIC wholesale, the extension hooks four published or
well-known BASIC indirect vectors. Likewise, the hardware drivers intercept
standard KERNAL I/O paths. This keeps much of Commodore's existing BASIC and
KERNAL machinery in use.

## How to read the annotated assembler listing

A typical instruction line in the companion listing has the form:

```
CPUADDR [ROM+offset] bytes       instruction              ; comment
```

For example, `ROM+0D0E` identifies a physical byte location in U1, while the
CPU address at the left shows where the instruction is intended to execute.
This distinction is essential because of the BusCard's unusual ROM mapping.

Data is represented with `.byte`, `.word`, or `.res` rather than being forced
through the 6502 instruction decoder. Long verified runs of zero bytes are
shown with `.res` for readability, but every byte of the original 8192-byte
EPROM is accounted for.

The final portion of the listing is headed as a *derived runtime image*. It is
not part of the EPROM address space. It is a reconstruction of the BASIC 4.0
extension after the ROM's relocation algorithm has processed the encoded data
for the normal `MEMSIZ=$A000` case.

Names beginning with descriptive terms such as `BASIC4_`, `MON_`,
`KERNAL_`, and `BUSCARD_` were assigned during reverse engineering; they are
not original Batteries Included source labels.

## Limits of the present reverse engineering

A great deal of U1 can be identified with high confidence because it connects
to standard C64 vectors, contains recognizable strings or tables, or performs
clearly identifiable hardware accesses. Some areas remain less certain.

In particular, the low-level IEEE-488 and parallel-printer code contains
numerous small handshake routines whose broad purpose is clear from the 8255
signals and their callers, but whose exact individual semantic names have not
all been established. The annotated listing intentionally preserves generic
labels in these cases.

Similarly, the U1 ROM does not by itself disclose the contents of the optional
U13-U15 EPROMs. Hardware behavior can tell us how those ROMs were intended to
be selected, but not the bytes that Batteries Included originally supplied in
them.

The listing should therefore be regarded as a documented reverse-engineering
work in progress, with a distinction between observations directly supported
by the ROM and hardware and interpretations inferred from context.

## Further areas for investigation

Several useful extensions to this work would be possible:

1. Trace each low-level IEEE-488 state transition against the schematic and
   IEEE-488 handshake sequence, allowing the remaining generic I/O routine
   names to be replaced with more precise functional names.
2. Identify the exact role of each BusCard DIP switch in the firmware and
   correlate each branch of the interface-selection code with the documented
   switch settings.
3. Compare the BASIC 4.0 command handlers in detail with Commodore PET/CBM
   BASIC 4.0 implementations to distinguish copied concepts from independent
   Batteries Included implementations.
4. Locate surviving U13-U15 ROM dumps or documentation for the optional 24K
   BASIC 4.0 package and determine exactly how that feature interacts with U1.
5. Compare other BusCard firmware revisions, if they can be found, against
   revision 0.9 to identify bug fixes or feature changes.
6. Test the reconstructed behavior in MAME or on physical hardware and use
   execution traces to validate the remaining uncertain routine descriptions.

## References used in the reverse engineering

- BusCard U1 annotated 6502 listing accompanying this document.
- BusCard schematic and related design material in the BusCard repository.
- MAME BusCard implementation:
  `https://github.com/mamedev/mame/blob/master/src/devices/bus/c64/buscard.cpp`
- C64 KERNAL disassembly at Zimmers.net:
  `https://www.zimmers.net/anonftp/pub/cbm/src/c64/c64_kernal_disassembly.txt`
- PET BASIC 4.0 disassembly at Zimmers.net:
  `https://zimmers.net/anonftp/pub/cbm/src/pet/pet_rom4_disassembly.txt`
- Commodore archive at Zimmers.net:
  `https://zimmers.net/anonftp/pub/cbm/`

## Summary

The BusCard U1 EPROM is considerably more sophisticated than a simple
peripheral driver ROM. Its 8K image combines a machine-language monitor, an
IEEE-488/parallel-printer I/O subsystem, a carefully constructed partial C64
KERNAL overlay, and an encoded relocatable BASIC command extension.

The firmware's architecture is especially notable for the way it integrates
with the C64 rather than attempting to replace it. It intercepts existing
KERNAL device operations, preserves the stock KERNAL bytes that must remain
visible under the ROM overlay, hooks standard BASIC vectors, and relocates its
BASIC extension below the current top of BASIC memory. The result is a card
whose additional hardware and software can be used through familiar C64
interfaces while still providing a substantial machine-language monitor and
BASIC 4.0-style disk-command environment.

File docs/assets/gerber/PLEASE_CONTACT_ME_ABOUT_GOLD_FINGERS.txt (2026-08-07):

I would like gold fingers for the card edges. Please contact me and let me know how much it will cost.

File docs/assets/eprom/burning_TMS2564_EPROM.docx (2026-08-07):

Procedure to Copy BusCard TMS2564 EPROM Using Promenade C1

1. Erase EPROM as per datasheet.

2. Tape over UV window of EPROM with opaque tape.

3. Plug in Promenade Model C1.

4. Turn on C64.

5. Turn on 1541 disc drive.

6. Put in Promos disc (Promenade software).

7. LOAD”PROMOS*64”,8

8. RUN

9. Z (this zeroes the Promenade)

10. Put in original BusCard EPROM, lock ZIF socket.

11. £ 8192,16383,0,20

12. Remove original BusCard EPROM from Promenade’s ZIF socket.

13. Put blank TMS2564 EPROM in Promenade’s ZIF socket and lock.

14. π 8192,16383,0,20,7

15. Remove newly burned EPROM from Promenade.

16. Done.

Procedure to Save BusCard TMS2564 EPROM Data to Disc Using Micromon

1. Plug in Promenade Model C1.

2. Turn on C64.

3. Turn on 1541 disc drive.

4. Put in disc with micromon.

5. Load”micromon”,8,1

6. NEW

7. Remove micromon disc.

8. Put in Promos disc (Promenade software).

9. Load”PROMOS*64”,8

10. RUN

11. Z

12. Put in original BusCard EPROM, lock ZIF socket.

13. £ 8192,16383,0,20

14. Remove original BusCard EPROM from Promenade’s ZIF socket.

15. SYS49152

16. Put empty disc in 1541 disc drive.

17. .S 2000 4000 “BUSCARD” 8

18. Remove first 2 bytes from file. See C program on next page.

19. Done.

Unlike the usage of Promos, when saving data in monitor you must give end address + 1 byte.

Therefore, we use 0x4000 and not 0x3fff.

8192d = 0x2000

16383d = 0x3fff

49152d = 0xc000

C Program (strip.c) to Remove First 2 Bytes of a File

// gcc -Wall strip.c

// ./a.out inputfilename.prg outputfilename.bin

#include <stdio.h>

#include <stdlib.h>

int

main (int argc, char **argv)

{

int val;

FILE *fi, *fo;

fi = fopen (argv[1], "rb");

if (fi == NULL) {

printf ("Can't open input file %s.\n", argv[1]);

exit (EXIT_FAILURE);

}

fo = fopen (argv[2], "wb");

if (fo == NULL) {

printf ("Can't open output file %s.\n", argv[2]);

exit (EXIT_FAILURE);

}

fgetc (fi);

fgetc (fi);

while ((val = fgetc (fi)) != EOF) {

fputc (val, fo);

}

fclose (fi);

fclose (fo);

return (EXIT_SUCCESS);

}

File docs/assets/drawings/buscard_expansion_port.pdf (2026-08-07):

## BusCard (Revision A) Commodore 64 Expansion Port

Looking toward BusCard edge from outside:

BusCard C64 Expansion
Port Card Edge
Contact # | Signal | Mnemonic (! = invert)

1 --------------System Ground--------------------GND
2 --------------+5 VDC---------------------------VCC
3 --------------+5 VDC---------------------------VCC
4 --------------Interrupt Request Line to 6510---!IRQ
5 --------------Read/Write-----------------------R/!W
6 --------------8.18 MHz Video Dot Clock---------Dot Clock 7 --------------I/O Block 1 $DE00-$DEFF----------I/O 1
8 --------------Memory Redirection---------------!GAME
9 --------------Memory Redirection---------------!EXROM 10 -------------I/O Block 2 $DF00-$DFFF----------I/O 2 11 -------------8K Decoded RAM/ROM at $8000------!ROML 12 -------------Bus Available Signal from VIC-II-BA
13 -------------Direct Memory Access Required----!DMA 14 -------------Data Bus Bit 7-------------------D7 15 -------------Data Bus Bit 6-------------------D6 16 -------------Data Bus Bit 5-------------------D5 17 -------------Data Bus Bit 4-------------------D4 18 -------------Data Bus Bit 3-------------------D3 19 -------------Data Bus Bit 2-------------------D2 20 -------------Data Bus Bit 1-------------------D1 21 -------------Data Bus Bit 0-------------------D0 22 -------------System Ground--------------------GND

Contacts are assigned as follows:

A

1 | 2 | 3 | 4
B | C | D
5 | 6 | 7
E | F | H
8 | 9 | 10
J | K | L
11 | 12
M | N

Top Side of Circuit Board

Bottom Side of Circuit Board

13 | 14 | 15 | 16 | 17 | 18 | 19 | 20 | 21 | 22
P | R | S | T | U | V | W | X | Y | Z

Page 1/2

BusCard C64 Expansion
Port Card Edge
Contact # | Signal | Mnemonic (! = invert)

A --------------System Ground--------------------GND
B --------------8K DECODED RAM/ROM at $E000------!ROMH
C --------------6510 RESET-----------------------!RESET
D --------------6510 Non-Maskable Interrupt------!NMI E --------------Phase 2 System Clock-------------Φ2
F --------------Address Bus Bit 15---------------A15 H --------------Address Bus Bit 14---------------A14 J --------------Address Bus Bit 13---------------A13 K --------------Address Bus Bit 12---------------A12 L --------------Address Bus Bit 11---------------A11 M --------------Address Bus Bit 10---------------A10 N --------------Address Bus Bit 9----------------A9 P --------------Address Bus Bit 8----------------A8 R --------------Address Bus Bit 7----------------A7 S --------------Address Bus Bit 6----------------A6 T --------------Address Bus Bit 5----------------A5 U --------------Address Bus Bit 4----------------A4 V --------------Address Bus Bit 3----------------A3 W --------------Address Bus Bit 2----------------A2 X --------------Address Bus Bit 1----------------A1 Y --------------Address Bus Bit 0----------------A0 Z --------------System Ground--------------------GND

Contact Properties:

0.05" x 0.35" contacts on a 0.1" (2.54 mm) contact spacing (pitch) 0.2" (5.08 mm) row spacing

Printed circuit board thickness is 0.062" (1.57 mm)

Page 2/2

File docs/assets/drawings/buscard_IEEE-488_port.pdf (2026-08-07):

## BusCard (Revision A) IEEE-488 Port

Looking toward BusCard edge from outside:

BusCard IEEE-488 | IEEE-488
Port Card Edge | | | Device
Contact # | Signal | Mnemonic | Pin #

1 --------------Data Input/Output Line 1---------DIO1------------- 1 2 --------------Data Input/Output Line 2---------DIO2------------- 2 3 --------------Data Input/Output Line 3---------DIO3------------- 3 4 --------------Data Input/Output Line 4---------DIO4------------- 4 5 --------------End or Identity------------------EOI-------------- 5 6 --------------Data Valid-----------------------DAV-------------- 6 7 --------------Not Ready for Data---------------NRFD------------- 7 8 --------------Not Data Accepted----------------NDAC------------- 8 9 --------------Interface Clear------------------IFC-------------- 9 10 -------------Service Request------------------SRQ------------- 10 11 -------------Attention------------------------ATN------------- 11 12 -------------Chassis GND (IEEE cable shield)--SHIELD---------- 12 A --------------Data Input/Output Line 5---------DIO5------------ 13 B --------------Data Input/Output Line 6---------DIO6------------ 14 C --------------Data Input/Output Line 7---------DIO7------------ 15 D --------------Data Input/Output Line 8---------DIO8------------ 16 E --------------Remote Enable--------------------REN------------- 17 F --------------DAV Ground-----------------------GND------------- 18 H --------------NRFD Ground----------------------GND------------- 19 J --------------NDAC Ground----------------------GND------------- 20 K --------------IFC Ground-----------------------GND------------- 21 L --------------SRQ Ground-----------------------GND------------- 22 M --------------ATN Ground-----------------------GND------------- 23 N --------------Data Ground (DIO1-8)-------------GND------------- 24

Contacts are assigned as follows:

Contact Properties:

0.09" x 0.35" contacts on a 0.156" (3.96 mm) contact spacing (pitch) 0.2" (5.08 mm) row spacing

Printed circuit board thickness is 0.062" (1.57 mm)

A

1 | 2 | 3 | 4
B | C | D
5 | 6 | 7
E | F | H
8 | 9 | 10
J | K | L
11 | 12
M | N

Top Side of Circuit Board

Bottom Side of Circuit Board

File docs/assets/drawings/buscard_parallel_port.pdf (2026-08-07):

1

2 | 4 | 6 | 8
3 | 5 | 7
10 | 12 | 14
9 | 11 | 13
16 | 18 | 20
15 | 17 | 19
22 | 24
21 | 23

26

25

## BusCard (Revision A) Parallel Printer Port

Looking toward BusCard edge from outside:

BusCard Parallel
Port Card Edge | | Printer
Contact # | Signal | Pin #

1 ---------------------Strobe------------------------- 1 3 ---------------------Data bit 0--------------------- 2 5 ---------------------Data bit 1--------------------- 3 7 ---------------------Data bit 2--------------------- 4 9 ---------------------Data bit 3--------------------- 5 11 --------------------Data bit 4--------------------- 6 13 --------------------Data bit 5--------------------- 7 15 --------------------Data bit 6--------------------- 8 17 --------------------Data bit 7--------------------- 9 19 --------------------N/C--------------------------- 10 21 --------------------Busy-------------------------- 11 23 --------------------N/C--------------------------- 12 25 --------------------N/C--------------------------- 13

Top Side of Circuit Board

Bottom Side of Circuit Board

All contacts on top of circuit board are grounded.

Bottom contacts are assigned as follows:

Contact Properties:

0.05" x 0.35" contacts on a 0.1" (2.54 mm) contact spacing (pitch) 0.2" (5.08 mm) row spacing

Printed circuit board thickness is 0.062" (1.57 mm)

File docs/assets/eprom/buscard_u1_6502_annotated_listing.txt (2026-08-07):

Batteries Included BusCard U1 ROM -- Annotated 6502 Disassembly
==============================================================================

Input image: buscardv0.9-tms2564.bin
Size:        8192 bytes ($2000; one TMS2564 8K x 8 EPROM)
CRC32:       175e8c96
SHA-1:       8fb4ba7e3d0b58dc01b66ef962955596f1b125b5
SHA-256:     c96f1b19aacd3f05fcd539c76dd476613d680c0ef03d7c26725a7e40a99e851a

This is a reverse-engineered annotated listing, NOT the original Batteries
Included source code.  Descriptive labels and comments were inferred from the
ROM, the BusCard schematic/hardware, standard C64 memory/KERNAL conventions,
MAME's BusCard hardware model, and comparison with published Commodore
disassemblies.  Where a purpose is not certain, the comments say so rather
than inventing an original symbol/name.

The image hash exactly matches the ROM called "0.9.u1" in current MAME:
  CRC 175e8c96, SHA1 8fb4ba7e3d0b58dc01b66ef962955596f1b125b5

Reference material used for interpretation:
  MAME BusCard model:
    https://github.com/mamedev/mame/blob/master/src/devices/bus/c64/buscard.cpp
  C64 KERNAL disassembly (Zimmers):
    https://www.zimmers.net/anonftp/pub/cbm/src/c64/c64_kernal_disassembly.txt
  PET BASIC 4.0 disassembly (Zimmers), useful for command-set comparison:
    https://zimmers.net/anonftp/pub/cbm/src/pet/pet_rom4_disassembly.txt

IMPORTANT ADDRESS-MAPPING NOTE
------------------------------------------------------------------------------
U1 is physically linear, but it is NOT used as one simple CPU-address-linear
program.  The BusCard decode logic gives it two important views:

  ROM offset       CPU address       Main contents
  $0000-$0BFF  ->  $A000-$ABFF      machine-language monitor + I/O drivers
  $0C00-$0FFF  ->  $EC00-$EFFF      resident C64 KERNAL overlay/dispatch code
  $1000-$113B  ->  $B000-$B13B      BASIC4 installer/uninstaller + small data
  $113C-$147A  ->  $B13C-$B47A      zero fill (831 bytes)
  $147B-$1FFF  ->  $B47B-$BFFF      encoded relocatable BASIC4 extension

MAME independently models U1 as always visible at $EC00-$EFFF (physical
offsets $0C00-$0FFF) when HIRAM is active, and as selectable over $A000-$BFFF.
That hardware fact is essential: blindly disassembling all 8192 bytes as if
they lived contiguously at $A000 would give wrong addresses for the resident
$EC00-$EFFF code.

PUBLIC ENTRYPOINTS
------------------------------------------------------------------------------
  SYS 61000 = $EE48 : enable/install BusCard BASIC 4.0 command extension
  SYS 61003 = $EE4B : disable/uninstall the BASIC 4.0 extension
  SYS 61006 = $EE4E : enter the BusCard machine-language monitor

The BASIC4 extension is not stored as directly executable code in the tail of
the EPROM.  $B47B-$BFFF is an encoded relocation stream.  On a normal stock
C64 with MEMSIZ=$A000 the installer expands it downward to $955B-$9FFF (2725
bytes; the stream contains 154 relocation records.  It installs four BASIC
vectors to its first four JMP stubs.  A fully
decoded listing of that derived runtime image is appended after the raw ROM.

BASIC4 KEYWORDS FOUND IN THE RELOCATED IMAGE
------------------------------------------------------------------------------
  CONCAT, DOPEN, DCLOSE, RECORD, HEADER, COLLECT, BACKUP, COPY, APPEND,
  DSAVE, DLOAD, CATALOG, RENAME, SCRATCH, DIRECTORY

MONITOR COMMAND DISPATCH TABLE
------------------------------------------------------------------------------
   :  $A140  memory-edit line
   ;  $A133  display/edit line helper
   R  $A0C5  register display
   M  $A0EB  memory display/modify
   G  $A154  go/execute
   X  $A184  exit monitor
   L  $A1EA  load memory
   S  $A207  save memory
   T  $A32F  transfer memory
   F  $A383  fill memory
   H  $A3B1  hunt/search
   D  $A424  disassemble
   P  $A542  print disassembly
   ,  $A56C  assembler/edit continuation helper
   A  $A58E  assemble one line

8255 PPI AT $DEC0-$DEC3 (from schematic + MAME hardware model)
------------------------------------------------------------------------------
  $DEC0 Port A : IEEE-488 DIO0-DIO7; also Centronics D0-D7; DIP read when selected
  $DEC1 Port B : PB0/PB1 ROM bank bits; PB3 BASIC-ROM enable; PB6 printer STROBE;
                   PB7 DIP-switch select
  $DEC2 Port C : PC0 printer BUSY; IEEE DAV/EOI/ATN/NRFD/NDAC and TE control
  $DEC3 Control: 8255 mode-control and bit-set/reset operations

LISTING FORMAT
------------------------------------------------------------------------------
  CPUADDR [ROM+offset] bytes       label / instruction                 ; comment
Data blocks use .byte/.word/.res.  .res is used only for a verified run of
identical zero bytes, so every byte of the original 8192-byte image is still
represented by the listing.

RAW U1 EPROM LISTING
==============================================================================

; ==========================================================================
; U1 physical $0000-$0BFF -> CPU $A000-$ABFF
; Machine-language monitor, then BusCard I/O drivers
; ==========================================================================

; --------------------------------------------------------------------------
; Machine-language monitor BRK entry. SYS 61006 first installs $ED8B as the
; BRK vector and deliberately executes BRK.  The BRK frame plus A/X/Y are
; unwound here into $0239-$023F.  The saved PC is reduced by two so the
; monitor reports the address of the BRK instruction rather than the byte after it.
; --------------------------------------------------------------------------
MONITOR_BRK_ENTRY:
A000 [ROM+0000] D8         CLD                                ; 6502 decimal mode off before monitor work
A001 [ROM+0001] 58         CLI                                ; allow IRQs while monitor runs
L_A002:
A002 [ROM+0002] 68         PLA                                ; pop Y saved by BRK/KERNAL entry frame
A003 [ROM+0003] 8D 3E 02   STA MON_YR                         ; save Y; monitor saved Y register
A006 [ROM+0006] 68         PLA                                ; pop X
A007 [ROM+0007] 8D 3D 02   STA MON_XR                         ; save X; monitor saved X register
A00A [ROM+000A] 68         PLA                                ; pop accumulator
A00B [ROM+000B] 8D 3C 02   STA MON_AC                         ; save A; monitor saved accumulator
A00E [ROM+000E] 68         PLA                                ; pop processor status
A00F [ROM+000F] 8D 3B 02   STA MON_SR                         ; save SR; monitor saved status register
A012 [ROM+0012] 68         PLA                                ; pop return-PC low byte
A013 [ROM+0013] AA         TAX                               
A014 [ROM+0014] 68         PLA                                ; pop return-PC high byte
A015 [ROM+0015] A8         TAY                               
A016 [ROM+0016] 38         SEC                                ; prepare to subtract 2 from BRK return PC
A017 [ROM+0017] 8A         TXA                               
A018 [ROM+0018] E9 02      SBC #$02                          
A01A [ROM+001A] 8D 3A 02   STA MON_PC_LO                      ; save adjusted PC low; monitor saved PC low
A01D [ROM+001D] 98         TYA                               
A01E [ROM+001E] E9 00      SBC #$00                          
A020 [ROM+0020] 8D 39 02   STA MON_PC_HI                      ; save adjusted PC high; monitor saved PC high
A023 [ROM+0023] BA         TSX                                ; capture stack pointer after frame removal
A024 [ROM+0024] 8E 3F 02   STX MON_SP                         ; monitor saved stack pointer
A027 [ROM+0027] 20 3D A5   JSR MON_PRINT_CR                   ; print CR; call/jump to mon print cr
A02A [ROM+002A] A2 42      LDX #$42                          
A02C [ROM+002C] A9 2A      LDA #$2A                          
A02E [ROM+002E] 20 4C A2   JSR MON_PRINT_TWO_CHARS            ; call/jump to mon print two chars
A031 [ROM+0031] A9 52      LDA #$52                           ; seed command path with R (register display)
A033 [ROM+0033] D0 2A      BNE MON_DISPATCH_COMMAND          
MON_INC_PTR:
A035 [ROM+0035] E6 C1      INC $C1                           
A037 [ROM+0037] D0 06      BNE L_A03F                        
A039 [ROM+0039] E6 C2      INC $C2                           
A03B [ROM+003B] D0 02      BNE L_A03F                        
A03D [ROM+003D] E6 26      INC $26                           
L_A03F:
A03F [ROM+003F] 60         RTS                                ; return
MON_GET_CHAR:
A040 [ROM+0040] 20 CF FF   JSR CHRIN                          ; read one character via KERNAL CHRIN; KERNAL CHRIN
A043 [ROM+0043] C9 0D      CMP #$0D                           ; CR ends the current monitor input item
A045 [ROM+0045] D0 F8      BNE L_A03F                        
A047 [ROM+0047] 68         PLA                                ; restore/pull byte from stack
A048 [ROM+0048] 68         PLA                                ; restore/pull byte from stack

; --------------------------------------------------------------------------
; Interactive monitor command prompt and dispatcher.  Commands are matched
; against the table at $A78E and dispatched through an address-minus-one table
; at $A79D using the classic PHA/PHA/RTS computed-call idiom.
; --------------------------------------------------------------------------
MON_COMMAND_LOOP:
A049 [ROM+0049] A9 00      LDA #$00                          
A04B [ROM+004B] 85 26      STA $26                           
A04D [ROM+004D] A2 0D      LDX #$0D                           ; monitor prompt begins with dot/period
A04F [ROM+004F] A9 2E      LDA #$2E                          
A051 [ROM+0051] 20 4C A2   JSR MON_PRINT_TWO_CHARS            ; call/jump to mon print two chars
L_A054:
A054 [ROM+0054] 20 40 A0   JSR MON_GET_CHAR                   ; call/jump to mon get char
A057 [ROM+0057] C9 2E      CMP #$2E                          
A059 [ROM+0059] F0 F9      BEQ L_A054                        
A05B [ROM+005B] C9 20      CMP #$20                          
A05D [ROM+005D] F0 F5      BEQ L_A054                        
MON_DISPATCH_COMMAND:
A05F [ROM+005F] A2 0E      LDX #$0E                           ; start reverse scan of 15 command characters
L_A061:
A061 [ROM+0061] DD 8E A7   CMP MON_COMMAND_CHARS,X           
A064 [ROM+0064] D0 0C      BNE L_A072                        
A066 [ROM+0066] 8A         TXA                               
A067 [ROM+0067] 0A         ASL A                             
A068 [ROM+0068] AA         TAX                               
A069 [ROM+0069] BD 9E A7   LDA $A79E,X                        ; push handler high byte (stored as address-1)
A06C [ROM+006C] 48         PHA                                ; save A on stack
A06D [ROM+006D] BD 9D A7   LDA MON_COMMAND_VECTORS_MINUS1,X   ; push handler low byte (stored as address-1)
A070 [ROM+0070] 48         PHA                                ; save A on stack
A071 [ROM+0071] 60         RTS                                ; RTS adds one, producing a computed subroutine dispatch
L_A072:
A072 [ROM+0072] CA         DEX                               
A073 [ROM+0073] 10 EC      BPL L_A061                        
A075 [ROM+0075] 4C E2 A2   JMP MON_SYNTAX_ERROR               ; call/jump to mon syntax error
MON_SAVE_ADDR:
A078 [ROM+0078] A5 C1      LDA $C1                           
A07A [ROM+007A] 8D 3A 02   STA MON_PC_LO                      ; monitor saved PC low
A07D [ROM+007D] A5 C2      LDA $C2                           
A07F [ROM+007F] 8D 39 02   STA MON_PC_HI                      ; monitor saved PC high
A082 [ROM+0082] 60         RTS                                ; return
MON_DUMP_8_BYTES:
A083 [ROM+0083] A9 08      LDA #$08                          
L_A085:
A085 [ROM+0085] 85 1D      STA $1D                           
A087 [ROM+0087] A0 00      LDY #$00                          
L_A089:
A089 [ROM+0089] 20 3A A5   JSR MON_PRINT_SPACE                ; call/jump to mon print space
A08C [ROM+008C] B1 C1      LDA ($C1),Y                       
A08E [ROM+008E] 20 3D A2   JSR MON_PRINT_HEX_BYTE             ; call/jump to mon print hex byte
A091 [ROM+0091] 20 35 A0   JSR MON_INC_PTR                    ; call/jump to mon inc ptr
A094 [ROM+0094] C6 1D      DEC $1D                           
A096 [ROM+0096] D0 F1      BNE L_A089                        
A098 [ROM+0098] 60         RTS                                ; return
MON_STORE_BYTE:
A099 [ROM+0099] 20 7D A2   JSR MON_PARSE_HEX_BYTE             ; call/jump to mon parse hex byte
A09C [ROM+009C] 90 0B      BCC L_A0A9                        
A09E [ROM+009E] A2 00      LDX #$00                          
A0A0 [ROM+00A0] 81 C1      STA ($C1,X)                       
A0A2 [ROM+00A2] C1 C1      CMP ($C1,X)                       
A0A4 [ROM+00A4] F0 03      BEQ L_A0A9                        
A0A6 [ROM+00A6] 4C E2 A2   JMP MON_SYNTAX_ERROR               ; call/jump to mon syntax error
L_A0A9:
A0A9 [ROM+00A9] 20 35 A0   JSR MON_INC_PTR                    ; call/jump to mon inc ptr
A0AC [ROM+00AC] C6 1D      DEC $1D                           
A0AE [ROM+00AE] 60         RTS                                ; return
MON_SELECT_SAVED_REGS:
A0AF [ROM+00AF] A9 3B      LDA #$3B                          
A0B1 [ROM+00B1] 85 C1      STA $C1                           
A0B3 [ROM+00B3] A9 02      LDA #$02                          
A0B5 [ROM+00B5] 85 C2      STA $C2                           
A0B7 [ROM+00B7] A9 05      LDA #$05                          
A0B9 [ROM+00B9] 60         RTS                                ; return
MON_PRINT_PREFIX:
A0BA [ROM+00BA] 98         TYA                               
A0BB [ROM+00BB] 48         PHA                                ; save A on stack
A0BC [ROM+00BC] 20 3D A5   JSR MON_PRINT_CR                   ; call/jump to mon print cr
A0BF [ROM+00BF] 68         PLA                                ; restore/pull byte from stack
A0C0 [ROM+00C0] A2 2E      LDX #$2E                          
A0C2 [ROM+00C2] 4C 4C A2   JMP MON_PRINT_TWO_CHARS            ; call/jump to mon print two chars

; --------------------------------------------------------------------------
; Monitor R command: print the saved PC, SR, A, X, Y and SP values.
; --------------------------------------------------------------------------
MON_CMD_R_REGISTERS:
A0C5 [ROM+00C5] A2 00      LDX #$00                          
L_A0C7:
A0C7 [ROM+00C7] BD BD A7   LDA MON_REGISTER_HEADER,X          ; read register-header character
A0CA [ROM+00CA] 20 D2 FF   JSR CHROUT                         ; print it; KERNAL CHROUT
A0CD [ROM+00CD] E8         INX                               
A0CE [ROM+00CE] E0 16      CPX #$16                          
A0D0 [ROM+00D0] D0 F5      BNE L_A0C7                        
A0D2 [ROM+00D2] A0 3B      LDY #$3B                          
A0D4 [ROM+00D4] 20 BA A0   JSR MON_PRINT_PREFIX               ; call/jump to mon print prefix
A0D7 [ROM+00D7] AD 39 02   LDA MON_PC_HI                      ; monitor saved PC high
A0DA [ROM+00DA] 20 3D A2   JSR MON_PRINT_HEX_BYTE             ; call/jump to mon print hex byte
A0DD [ROM+00DD] AD 3A 02   LDA MON_PC_LO                      ; monitor saved PC low
A0E0 [ROM+00E0] 20 3D A2   JSR MON_PRINT_HEX_BYTE             ; call/jump to mon print hex byte
A0E3 [ROM+00E3] 20 AF A0   JSR MON_SELECT_SAVED_REGS          ; call/jump to mon select saved regs
A0E6 [ROM+00E6] 20 85 A0   JSR L_A085                        
A0E9 [ROM+00E9] F0 66      BEQ MON_TO_PROMPT                 

; --------------------------------------------------------------------------
; Monitor M command: display memory and optionally accept edited hex bytes.
; --------------------------------------------------------------------------
MON_CMD_M_MEMORY:
A0EB [ROM+00EB] 20 40 A0   JSR MON_GET_CHAR                   ; call/jump to mon get char
A0EE [ROM+00EE] 20 6E A2   JSR MON_PARSE_HEX_WORD             ; call/jump to mon parse hex word
A0F1 [ROM+00F1] 90 3D      BCC L_A130                        
A0F3 [ROM+00F3] 20 5E A2   JSR MON_SWAP_ADDR_PAIRS            ; call/jump to mon swap addr pairs
A0F6 [ROM+00F6] 20 CF FF   JSR CHRIN                          ; KERNAL CHRIN
A0F9 [ROM+00F9] C9 0D      CMP #$0D                          
A0FB [ROM+00FB] D0 0B      BNE L_A108                        
A0FD [ROM+00FD] A5 C3      LDA $C3                           
A0FF [ROM+00FF] 85 C1      STA $C1                           
A101 [ROM+0101] A5 C4      LDA $C4                           
A103 [ROM+0103] 85 C2      STA $C2                           
A105 [ROM+0105] 4C 10 A1   JMP L_A110                        
L_A108:
A108 [ROM+0108] 20 6E A2   JSR MON_PARSE_HEX_WORD             ; call/jump to mon parse hex word
A10B [ROM+010B] 90 23      BCC L_A130                        
A10D [ROM+010D] 20 5E A2   JSR MON_SWAP_ADDR_PAIRS            ; call/jump to mon swap addr pairs
L_A110:
A110 [ROM+0110] 20 E1 FF   JSR STOP                           ; KERNAL STOP
A113 [ROM+0113] F0 3C      BEQ MON_TO_PROMPT                 
A115 [ROM+0115] A6 26      LDX $26                           
A117 [ROM+0117] D0 38      BNE MON_TO_PROMPT                 
A119 [ROM+0119] A5 C3      LDA $C3                           
A11B [ROM+011B] C5 C1      CMP $C1                           
A11D [ROM+011D] A5 C4      LDA $C4                           
A11F [ROM+011F] E5 C2      SBC $C2                           
A121 [ROM+0121] 90 2E      BCC MON_TO_PROMPT                 
A123 [ROM+0123] A0 3A      LDY #$3A                          
A125 [ROM+0125] 20 BA A0   JSR MON_PRINT_PREFIX               ; call/jump to mon print prefix
A128 [ROM+0128] 20 36 A2   JSR MON_PRINT_WORD                 ; call/jump to mon print word
A12B [ROM+012B] 20 83 A0   JSR MON_DUMP_8_BYTES               ; call/jump to mon dump 8 bytes
A12E [ROM+012E] F0 E0      BEQ L_A110                        
L_A130:
A130 [ROM+0130] 4C E2 A2   JMP MON_SYNTAX_ERROR               ; call/jump to mon syntax error

; --------------------------------------------------------------------------
; Monitor semicolon line handler.  It is part of the monitor display/edit syntax; the exact
; original command terminology is not present in the ROM, so the descriptive name is inferred.
; --------------------------------------------------------------------------
MON_CMD_SEMICOLON:
A133 [ROM+0133] 20 6E A2   JSR MON_PARSE_HEX_WORD             ; call/jump to mon parse hex word
A136 [ROM+0136] 90 03      BCC L_A13B                        
A138 [ROM+0138] 20 78 A0   JSR MON_SAVE_ADDR                  ; call/jump to mon save addr
L_A13B:
A13B [ROM+013B] 20 AF A0   JSR MON_SELECT_SAVED_REGS          ; call/jump to mon select saved regs
A13E [ROM+013E] D0 07      BNE L_A147                        

; --------------------------------------------------------------------------
; Monitor colon line handler: accepts hexadecimal byte data for memory modification.
; --------------------------------------------------------------------------
MON_CMD_COLON:
A140 [ROM+0140] 20 6E A2   JSR MON_PARSE_HEX_WORD             ; call/jump to mon parse hex word
A143 [ROM+0143] 90 EB      BCC L_A130                        
A145 [ROM+0145] A9 08      LDA #$08                          
L_A147:
A147 [ROM+0147] 85 1D      STA $1D                           
L_A149:
A149 [ROM+0149] 20 40 A0   JSR MON_GET_CHAR                   ; call/jump to mon get char
A14C [ROM+014C] 20 99 A0   JSR MON_STORE_BYTE                 ; call/jump to mon store byte
A14F [ROM+014F] D0 F8      BNE L_A149                        
MON_TO_PROMPT:
A151 [ROM+0151] 4C 49 A0   JMP MON_COMMAND_LOOP               ; call/jump to mon command loop

; --------------------------------------------------------------------------
; Monitor G (go) command.  Optionally accepts an address, rebuilds the saved
; processor stack frame/registers and exits through $EE6A, which restores the
; normal memory mapping before RTI.
; --------------------------------------------------------------------------
MON_CMD_G_GO:
A154 [ROM+0154] 20 CF FF   JSR CHRIN                          ; read remainder of G command line; KERNAL CHRIN
A157 [ROM+0157] C9 0D      CMP #$0D                          
A159 [ROM+0159] F0 0C      BEQ L_A167                        
A15B [ROM+015B] C9 20      CMP #$20                          
A15D [ROM+015D] D0 D1      BNE L_A130                        
A15F [ROM+015F] 20 6E A2   JSR MON_PARSE_HEX_WORD             ; call/jump to mon parse hex word
A162 [ROM+0162] 90 03      BCC L_A167                        
A164 [ROM+0164] 20 78 A0   JSR MON_SAVE_ADDR                  ; call/jump to mon save addr
L_A167:
A167 [ROM+0167] AE 3F 02   LDX MON_SP                         ; restore saved monitor stack pointer; monitor saved stack pointer
A16A [ROM+016A] 9A         TXS                               
A16B [ROM+016B] 78         SEI                                ; disable IRQs while rebuilding RTI frame
A16C [ROM+016C] AD 39 02   LDA MON_PC_HI                      ; monitor saved PC high
A16F [ROM+016F] 48         PHA                                ; save A on stack
A170 [ROM+0170] AD 3A 02   LDA MON_PC_LO                      ; monitor saved PC low
A173 [ROM+0173] 48         PHA                                ; save A on stack
A174 [ROM+0174] AD 3B 02   LDA MON_SR                         ; monitor saved status register
A177 [ROM+0177] 48         PHA                                ; save A on stack
A178 [ROM+0178] AD 3C 02   LDA MON_AC                         ; monitor saved accumulator
A17B [ROM+017B] AE 3D 02   LDX MON_XR                         ; monitor saved X register
A17E [ROM+017E] AC 3E 02   LDY MON_YR                         ; monitor saved Y register
A181 [ROM+0181] 4C 6A EE   JMP MONITOR_RTI_RESTORE            ; restore mapping then RTI through resident helper; call/jump to monitor rti restore

; --------------------------------------------------------------------------
; Monitor X command: restore the stack and return to BASIC through $EE42.
; --------------------------------------------------------------------------
MON_CMD_X_EXIT:
A184 [ROM+0184] AE 3F 02   LDX MON_SP                         ; restore saved monitor stack pointer; monitor saved stack pointer
A187 [ROM+0187] 9A         TXS                               
A188 [ROM+0188] 4C 42 EE   JMP RETURN_TO_UNDERLYING_BASIC     ; return to BASIC, not to saved BRK context; call/jump to return to underlying basic
MON_PARSE_FILENAME_DEVICE:
A18B [ROM+018B] A0 01      LDY #$01                          
A18D [ROM+018D] 84 BA      STY FA                             ; current device number
A18F [ROM+018F] 84 B9      STY SA                             ; secondary address
A191 [ROM+0191] 88         DEY                               
A192 [ROM+0192] 84 B7      STY FNLEN                          ; filename length
A194 [ROM+0194] 84 90      STY STATUS                         ; KERNAL I/O status byte
A196 [ROM+0196] 84 93      STY LOAD_VERIFY                    ; KERNAL LOAD/VERIFY flag
A198 [ROM+0198] A9 40      LDA #$40                          
A19A [ROM+019A] 85 BB      STA FNADR_LO                       ; filename pointer low
A19C [ROM+019C] A9 02      LDA #$02                          
A19E [ROM+019E] 85 BC      STA FNADR_HI                       ; filename pointer high
L_A1A0:
A1A0 [ROM+01A0] 20 CF FF   JSR CHRIN                          ; KERNAL CHRIN
A1A3 [ROM+01A3] C9 20      CMP #$20                          
A1A5 [ROM+01A5] F0 F9      BEQ L_A1A0                        
A1A7 [ROM+01A7] C9 0D      CMP #$0D                          
A1A9 [ROM+01A9] F0 38      BEQ L_A1E3                        
A1AB [ROM+01AB] C9 22      CMP #$22                          
L_A1AD:
A1AD [ROM+01AD] D0 14      BNE L_A1C3                        
L_A1AF:
A1AF [ROM+01AF] 20 CF FF   JSR CHRIN                          ; KERNAL CHRIN
A1B2 [ROM+01B2] C9 22      CMP #$22                          
A1B4 [ROM+01B4] F0 10      BEQ L_A1C6                        
A1B6 [ROM+01B6] C9 0D      CMP #$0D                          
A1B8 [ROM+01B8] F0 29      BEQ L_A1E3                        
A1BA [ROM+01BA] 91 BB      STA (FNADR_LO),Y                   ; filename pointer low
A1BC [ROM+01BC] E6 B7      INC FNLEN                          ; filename length
A1BE [ROM+01BE] C8         INY                               
A1BF [ROM+01BF] C0 10      CPY #$10                          
L_A1C1:
A1C1 [ROM+01C1] D0 EC      BNE L_A1AF                        
L_A1C3:
A1C3 [ROM+01C3] 4C E2 A2   JMP MON_SYNTAX_ERROR               ; call/jump to mon syntax error
L_A1C6:
A1C6 [ROM+01C6] 20 CF FF   JSR CHRIN                          ; KERNAL CHRIN
A1C9 [ROM+01C9] C9 0D      CMP #$0D                          
A1CB [ROM+01CB] F0 16      BEQ L_A1E3                        
A1CD [ROM+01CD] C9 2C      CMP #$2C                          
A1CF [ROM+01CF] D0 DC      BNE L_A1AD                        
A1D1 [ROM+01D1] 20 7D A2   JSR MON_PARSE_HEX_BYTE             ; call/jump to mon parse hex byte
A1D4 [ROM+01D4] 29 0F      AND #$0F                          
A1D6 [ROM+01D6] F0 E9      BEQ L_A1C1                        
A1D8 [ROM+01D8] C9 03      CMP #$03                          
A1DA [ROM+01DA] F0 E5      BEQ L_A1C1                        
A1DC [ROM+01DC] 85 BA      STA FA                             ; current device number
A1DE [ROM+01DE] 20 CF FF   JSR CHRIN                          ; KERNAL CHRIN
A1E1 [ROM+01E1] C9 0D      CMP #$0D                          
L_A1E3:
A1E3 [ROM+01E3] 60         RTS                                ; return
MON_CALL_LOAD_VECTOR:
A1E4 [ROM+01E4] 6C 30 03   JMP (ILOAD)                        ; jump through C64 monitor/KERNAL LOAD vector; indirect LOAD vector used by monitor
MON_CALL_SAVE_VECTOR:
A1E7 [ROM+01E7] 6C 32 03   JMP (ISAVE)                        ; jump through C64 monitor/KERNAL SAVE vector; indirect SAVE vector used by monitor

; --------------------------------------------------------------------------
; Monitor L command: parse filename/device/address and invoke the indirect LOAD vector.
; --------------------------------------------------------------------------
MON_CMD_L_LOAD:
A1EA [ROM+01EA] 20 8B A1   JSR MON_PARSE_FILENAME_DEVICE      ; call/jump to mon parse filename device
A1ED [ROM+01ED] F0 0A      BEQ L_A1F9                        
A1EF [ROM+01EF] 20 6E A2   JSR MON_PARSE_HEX_WORD             ; call/jump to mon parse hex word
A1F2 [ROM+01F2] 90 CF      BCC L_A1C3                        
A1F4 [ROM+01F4] 20 5E A2   JSR MON_SWAP_ADDR_PAIRS            ; call/jump to mon swap addr pairs
A1F7 [ROM+01F7] C6 B9      DEC SA                             ; secondary address
L_A1F9:
A1F9 [ROM+01F9] A9 00      LDA #$00                          
A1FB [ROM+01FB] 20 E4 A1   JSR MON_CALL_LOAD_VECTOR           ; call/jump to mon call load vector
A1FE [ROM+01FE] A5 90      LDA STATUS                         ; KERNAL I/O status byte
A200 [ROM+0200] 29 10      AND #$10                          
A202 [ROM+0202] D0 BF      BNE L_A1C3                        
A204 [ROM+0204] 4C 49 A0   JMP MON_COMMAND_LOOP               ; call/jump to mon command loop

; --------------------------------------------------------------------------
; Monitor S command: parse filename/device/start/end addresses and invoke SAVE.
; --------------------------------------------------------------------------
MON_CMD_S_SAVE:
A207 [ROM+0207] 20 8B A1   JSR MON_PARSE_FILENAME_DEVICE      ; call/jump to mon parse filename device
A20A [ROM+020A] C9 2C      CMP #$2C                          
A20C [ROM+020C] D0 B5      BNE L_A1C3                        
A20E [ROM+020E] 20 6E A2   JSR MON_PARSE_HEX_WORD             ; call/jump to mon parse hex word
A211 [ROM+0211] 20 5E A2   JSR MON_SWAP_ADDR_PAIRS            ; call/jump to mon swap addr pairs
A214 [ROM+0214] 20 CF FF   JSR CHRIN                          ; KERNAL CHRIN
A217 [ROM+0217] C9 2C      CMP #$2C                          
A219 [ROM+0219] D0 A8      BNE L_A1C3                        
A21B [ROM+021B] 20 6E A2   JSR MON_PARSE_HEX_WORD             ; call/jump to mon parse hex word
A21E [ROM+021E] A5 C1      LDA $C1                           
A220 [ROM+0220] 85 AE      STA $AE                           
A222 [ROM+0222] A5 C2      LDA $C2                           
A224 [ROM+0224] 85 AF      STA $AF                           
A226 [ROM+0226] 20 5E A2   JSR MON_SWAP_ADDR_PAIRS            ; call/jump to mon swap addr pairs
A229 [ROM+0229] 20 CF FF   JSR CHRIN                          ; KERNAL CHRIN
A22C [ROM+022C] C9 0D      CMP #$0D                          
A22E [ROM+022E] D0 93      BNE L_A1C3                        
A230 [ROM+0230] 20 E7 A1   JSR MON_CALL_SAVE_VECTOR           ; call/jump to mon call save vector
A233 [ROM+0233] 4C 49 A0   JMP MON_COMMAND_LOOP               ; call/jump to mon command loop
MON_PRINT_WORD:
A236 [ROM+0236] A5 C2      LDA $C2                           
A238 [ROM+0238] 20 3D A2   JSR MON_PRINT_HEX_BYTE             ; call/jump to mon print hex byte
A23B [ROM+023B] A5 C1      LDA $C1                           
MON_PRINT_HEX_BYTE:
A23D [ROM+023D] 48         PHA                                ; preserve byte while printing high nibble
A23E [ROM+023E] 4A         LSR A                             
A23F [ROM+023F] 4A         LSR A                             
A240 [ROM+0240] 4A         LSR A                             
A241 [ROM+0241] 4A         LSR A                             
A242 [ROM+0242] 20 55 A2   JSR MON_NIBBLE_TO_HEX              ; call/jump to mon nibble to hex
A245 [ROM+0245] AA         TAX                               
A246 [ROM+0246] 68         PLA                                ; restore/pull byte from stack
A247 [ROM+0247] 29 0F      AND #$0F                          
A249 [ROM+0249] 20 55 A2   JSR MON_NIBBLE_TO_HEX              ; call/jump to mon nibble to hex
MON_PRINT_TWO_CHARS:
A24C [ROM+024C] 48         PHA                                ; save A on stack
A24D [ROM+024D] 8A         TXA                               
A24E [ROM+024E] 20 D2 FF   JSR CHROUT                         ; KERNAL CHROUT
A251 [ROM+0251] 68         PLA                                ; restore/pull byte from stack
A252 [ROM+0252] 4C D2 FF   JMP CHROUT                         ; KERNAL CHROUT
MON_NIBBLE_TO_HEX:
A255 [ROM+0255] 09 30      ORA #$30                           ; turn nibble 0-15 into ASCII 0-9/A-F
A257 [ROM+0257] C9 3A      CMP #$3A                          
A259 [ROM+0259] 90 02      BCC L_A25D                        
A25B [ROM+025B] 69 06      ADC #$06                          
L_A25D:
A25D [ROM+025D] 60         RTS                                ; return
MON_SWAP_ADDR_PAIRS:
A25E [ROM+025E] A2 02      LDX #$02                          
L_A260:
A260 [ROM+0260] B5 C0      LDA $C0,X                         
A262 [ROM+0262] 48         PHA                                ; save A on stack
A263 [ROM+0263] B5 C2      LDA $C2,X                         
A265 [ROM+0265] 95 C0      STA $C0,X                         
A267 [ROM+0267] 68         PLA                                ; restore/pull byte from stack
A268 [ROM+0268] 95 C2      STA $C2,X                         
A26A [ROM+026A] CA         DEX                               
A26B [ROM+026B] D0 F3      BNE L_A260                        
A26D [ROM+026D] 60         RTS                                ; return
MON_PARSE_HEX_WORD:
A26E [ROM+026E] 20 7D A2   JSR MON_PARSE_HEX_BYTE             ; call/jump to mon parse hex byte
L_A271:
A271 [ROM+0271] 90 02      BCC L_A275                        
A273 [ROM+0273] 85 C2      STA $C2                           
L_A275:
A275 [ROM+0275] 20 7D A2   JSR MON_PARSE_HEX_BYTE             ; call/jump to mon parse hex byte
A278 [ROM+0278] 90 02      BCC L_A27C                        
A27A [ROM+027A] 85 C1      STA $C1                           
L_A27C:
A27C [ROM+027C] 60         RTS                                ; return
MON_PARSE_HEX_BYTE:
A27D [ROM+027D] A9 00      LDA #$00                          
A27F [ROM+027F] 85 2A      STA $2A                           
A281 [ROM+0281] 20 40 A0   JSR MON_GET_CHAR                   ; call/jump to mon get char
L_A284:
A284 [ROM+0284] C9 20      CMP #$20                          
A286 [ROM+0286] D0 09      BNE L_A291                        
A288 [ROM+0288] 20 40 A0   JSR MON_GET_CHAR                   ; call/jump to mon get char
A28B [ROM+028B] C9 20      CMP #$20                          
A28D [ROM+028D] D0 0E      BNE L_A29D                        
A28F [ROM+028F] 18         CLC                               
A290 [ROM+0290] 60         RTS                                ; return
L_A291:
A291 [ROM+0291] 20 A4 A2   JSR MON_ASCII_HEX_TO_NIBBLE        ; call/jump to mon ascii hex to nibble
A294 [ROM+0294] 0A         ASL A                             
A295 [ROM+0295] 0A         ASL A                             
A296 [ROM+0296] 0A         ASL A                             
A297 [ROM+0297] 0A         ASL A                             
A298 [ROM+0298] 85 2A      STA $2A                           
A29A [ROM+029A] 20 40 A0   JSR MON_GET_CHAR                   ; call/jump to mon get char
L_A29D:
A29D [ROM+029D] 20 A4 A2   JSR MON_ASCII_HEX_TO_NIBBLE        ; call/jump to mon ascii hex to nibble
A2A0 [ROM+02A0] 05 2A      ORA $2A                           
A2A2 [ROM+02A2] 38         SEC                               
A2A3 [ROM+02A3] 60         RTS                                ; return
MON_ASCII_HEX_TO_NIBBLE:
A2A4 [ROM+02A4] C9 3A      CMP #$3A                          
A2A6 [ROM+02A6] 90 02      BCC L_A2AA                        
A2A8 [ROM+02A8] 69 08      ADC #$08                          
L_A2AA:
A2AA [ROM+02AA] 29 0F      AND #$0F                          
A2AC [ROM+02AC] 60         RTS                                ; return
L_A2AD:
A2AD [ROM+02AD] A2 02      LDX #$02                          
A2AF [ROM+02AF] 2C A2 00   BIT $00A2                         
A2B2 [ROM+02B2] B4 C1      LDY $C1,X                         
A2B4 [ROM+02B4] D0 08      BNE L_A2BE                        
A2B6 [ROM+02B6] B4 C2      LDY $C2,X                         
A2B8 [ROM+02B8] D0 02      BNE L_A2BC                        
A2BA [ROM+02BA] E6 26      INC $26                           
L_A2BC:
A2BC [ROM+02BC] D6 C2      DEC $C2,X                         
L_A2BE:
A2BE [ROM+02BE] D6 C1      DEC $C1,X                         
L_A2C0:
A2C0 [ROM+02C0] 60         RTS                                ; return
MON_SKIP_SPACES:
A2C1 [ROM+02C1] 20 40 A0   JSR MON_GET_CHAR                   ; call/jump to mon get char
A2C4 [ROM+02C4] C9 20      CMP #$20                          
A2C6 [ROM+02C6] F0 F9      BEQ MON_SKIP_SPACES               
A2C8 [ROM+02C8] 60         RTS                                ; return
L_A2C9:
A2C9 [ROM+02C9] A9 00      LDA #$00                          
A2CB [ROM+02CB] 8D 00 01   STA $0100                         
A2CE [ROM+02CE] 20 C1 A2   JSR MON_SKIP_SPACES                ; call/jump to mon skip spaces
A2D1 [ROM+02D1] 20 84 A2   JSR L_A284                        
A2D4 [ROM+02D4] 20 71 A2   JSR L_A271                        
A2D7 [ROM+02D7] 90 09      BCC MON_SYNTAX_ERROR              
A2D9 [ROM+02D9] 60         RTS                                ; return
L_A2DA:
A2DA [ROM+02DA] 20 40 A0   JSR MON_GET_CHAR                   ; call/jump to mon get char
A2DD [ROM+02DD] 20 6E A2   JSR MON_PARSE_HEX_WORD             ; call/jump to mon parse hex word
A2E0 [ROM+02E0] B0 DE      BCS L_A2C0                        
MON_SYNTAX_ERROR:
A2E2 [ROM+02E2] AE 3F 02   LDX MON_SP                         ; monitor saved stack pointer
A2E5 [ROM+02E5] 9A         TXS                               
A2E6 [ROM+02E6] A9 3F      LDA #$3F                           ; print ? for monitor syntax/error indication
A2E8 [ROM+02E8] 20 D2 FF   JSR CHROUT                         ; KERNAL CHROUT
A2EB [ROM+02EB] 4C 49 A0   JMP MON_COMMAND_LOOP               ; call/jump to mon command loop
L_A2EE:
A2EE [ROM+02EE] 20 3A A5   JSR MON_PRINT_SPACE                ; call/jump to mon print space
A2F1 [ROM+02F1] CA         DEX                               
A2F2 [ROM+02F2] D0 FA      BNE L_A2EE                        
A2F4 [ROM+02F4] 60         RTS                                ; return
L_A2F5:
A2F5 [ROM+02F5] E6 C3      INC $C3                           
A2F7 [ROM+02F7] D0 02      BNE L_A2FB                        
A2F9 [ROM+02F9] E6 C4      INC $C4                           
L_A2FB:
A2FB [ROM+02FB] 60         RTS                                ; return
L_A2FC:
A2FC [ROM+02FC] A2 02      LDX #$02                          
L_A2FE:
A2FE [ROM+02FE] B5 C0      LDA $C0,X                         
A300 [ROM+0300] 48         PHA                                ; save A on stack
A301 [ROM+0301] B5 27      LDA $27,X                         
A303 [ROM+0303] 95 C0      STA $C0,X                         
A305 [ROM+0305] 68         PLA                                ; restore/pull byte from stack
A306 [ROM+0306] 95 27      STA $27,X                         
A308 [ROM+0308] CA         DEX                               
A309 [ROM+0309] D0 F3      BNE L_A2FE                        
A30B [ROM+030B] 60         RTS                                ; return
L_A30C:
A30C [ROM+030C] A5 C3      LDA $C3                           
A30E [ROM+030E] A4 C4      LDY $C4                           
A310 [ROM+0310] 38         SEC                               
A311 [ROM+0311] E9 02      SBC #$02                          
A313 [ROM+0313] B0 0E      BCS L_A323                        
A315 [ROM+0315] 88         DEY                               
A316 [ROM+0316] 90 0B      BCC L_A323                        
L_A318:
A318 [ROM+0318] A5 28      LDA $28                           
A31A [ROM+031A] A4 29      LDY $29                           
A31C [ROM+031C] 4C 23 A3   JMP L_A323                        
L_A31F:
A31F [ROM+031F] A5 C3      LDA $C3                           
A321 [ROM+0321] A4 C4      LDY $C4                           
L_A323:
A323 [ROM+0323] 38         SEC                               
A324 [ROM+0324] E5 C1      SBC $C1                           
A326 [ROM+0326] 85 1E      STA $1E                           
A328 [ROM+0328] 98         TYA                               
A329 [ROM+0329] E5 C2      SBC $C2                           
A32B [ROM+032B] A8         TAY                               
A32C [ROM+032C] 05 1E      ORA $1E                           
A32E [ROM+032E] 60         RTS                                ; return

; --------------------------------------------------------------------------
; Monitor T command: transfer/copy a range of memory.
; --------------------------------------------------------------------------
MON_CMD_T_TRANSFER:
A32F [ROM+032F] 20 C9 A2   JSR L_A2C9                        
A332 [ROM+0332] 20 5E A2   JSR MON_SWAP_ADDR_PAIRS            ; call/jump to mon swap addr pairs
A335 [ROM+0335] 20 DA A2   JSR L_A2DA                        
A338 [ROM+0338] 20 FC A2   JSR L_A2FC                        
A33B [ROM+033B] 20 DA A2   JSR L_A2DA                        
A33E [ROM+033E] 20 1F A3   JSR L_A31F                        
A341 [ROM+0341] 20 5E A2   JSR MON_SWAP_ADDR_PAIRS            ; call/jump to mon swap addr pairs
A344 [ROM+0344] 90 15      BCC L_A35B                        
L_A346:
A346 [ROM+0346] A6 26      LDX $26                           
A348 [ROM+0348] D0 64      BNE L_A3AE                        
A34A [ROM+034A] 20 18 A3   JSR L_A318                        
A34D [ROM+034D] 90 5F      BCC L_A3AE                        
A34F [ROM+034F] A1 C1      LDA ($C1,X)                       
A351 [ROM+0351] 81 C3      STA ($C3,X)                       
A353 [ROM+0353] 20 F5 A2   JSR L_A2F5                        
A356 [ROM+0356] 20 35 A0   JSR MON_INC_PTR                    ; call/jump to mon inc ptr
A359 [ROM+0359] D0 EB      BNE L_A346                        
L_A35B:
A35B [ROM+035B] 20 18 A3   JSR L_A318                        
A35E [ROM+035E] 18         CLC                               
A35F [ROM+035F] A5 1E      LDA $1E                           
A361 [ROM+0361] 65 C3      ADC $C3                           
A363 [ROM+0363] 85 C3      STA $C3                           
A365 [ROM+0365] 98         TYA                               
A366 [ROM+0366] 65 C4      ADC $C4                           
A368 [ROM+0368] 85 C4      STA $C4                           
A36A [ROM+036A] 20 FC A2   JSR L_A2FC                        
L_A36D:
A36D [ROM+036D] A6 26      LDX $26                           
A36F [ROM+036F] D0 3D      BNE L_A3AE                        
A371 [ROM+0371] A1 C1      LDA ($C1,X)                       
A373 [ROM+0373] 81 C3      STA ($C3,X)                       
A375 [ROM+0375] 20 18 A3   JSR L_A318                        
A378 [ROM+0378] B0 34      BCS L_A3AE                        
A37A [ROM+037A] 20 AD A2   JSR L_A2AD                        
A37D [ROM+037D] 20 B0 A2   JSR L_A2B0                        
A380 [ROM+0380] 4C 6D A3   JMP L_A36D                        

; --------------------------------------------------------------------------
; Monitor F command: fill a memory range with a byte value.
; --------------------------------------------------------------------------
MON_CMD_F_FILL:
A383 [ROM+0383] 20 C9 A2   JSR L_A2C9                        
A386 [ROM+0386] 20 5E A2   JSR MON_SWAP_ADDR_PAIRS            ; call/jump to mon swap addr pairs
A389 [ROM+0389] 20 DA A2   JSR L_A2DA                        
A38C [ROM+038C] 20 5E A2   JSR MON_SWAP_ADDR_PAIRS            ; call/jump to mon swap addr pairs
A38F [ROM+038F] 20 40 A0   JSR MON_GET_CHAR                   ; call/jump to mon get char
A392 [ROM+0392] 20 7D A2   JSR MON_PARSE_HEX_BYTE             ; call/jump to mon parse hex byte
A395 [ROM+0395] 90 14      BCC L_A3AB                        
A397 [ROM+0397] 85 1D      STA $1D                           
L_A399:
A399 [ROM+0399] A6 26      LDX $26                           
A39B [ROM+039B] D0 11      BNE L_A3AE                        
A39D [ROM+039D] 20 1F A3   JSR L_A31F                        
A3A0 [ROM+03A0] 90 0C      BCC L_A3AE                        
A3A2 [ROM+03A2] A5 1D      LDA $1D                           
A3A4 [ROM+03A4] 81 C1      STA ($C1,X)                       
A3A6 [ROM+03A6] 20 35 A0   JSR MON_INC_PTR                    ; call/jump to mon inc ptr
A3A9 [ROM+03A9] D0 EE      BNE L_A399                        
L_A3AB:
A3AB [ROM+03AB] 4C E2 A2   JMP MON_SYNTAX_ERROR               ; call/jump to mon syntax error
L_A3AE:
A3AE [ROM+03AE] 4C 49 A0   JMP MON_COMMAND_LOOP               ; call/jump to mon command loop

; --------------------------------------------------------------------------
; Monitor H command: hunt/search memory for a byte sequence.
; --------------------------------------------------------------------------
MON_CMD_H_HUNT:
A3B1 [ROM+03B1] 20 C9 A2   JSR L_A2C9                        
A3B4 [ROM+03B4] 20 5E A2   JSR MON_SWAP_ADDR_PAIRS            ; call/jump to mon swap addr pairs
A3B7 [ROM+03B7] 20 DA A2   JSR L_A2DA                        
A3BA [ROM+03BA] 20 5E A2   JSR MON_SWAP_ADDR_PAIRS            ; call/jump to mon swap addr pairs
A3BD [ROM+03BD] 20 40 A0   JSR MON_GET_CHAR                   ; call/jump to mon get char
A3C0 [ROM+03C0] A2 00      LDX #$00                          
A3C2 [ROM+03C2] 20 40 A0   JSR MON_GET_CHAR                   ; call/jump to mon get char
A3C5 [ROM+03C5] C9 27      CMP #$27                          
A3C7 [ROM+03C7] D0 14      BNE L_A3DD                        
A3C9 [ROM+03C9] 20 40 A0   JSR MON_GET_CHAR                   ; call/jump to mon get char
L_A3CC:
A3CC [ROM+03CC] 9D 10 02   STA $0210,X                       
A3CF [ROM+03CF] E8         INX                               
A3D0 [ROM+03D0] 20 CF FF   JSR CHRIN                          ; KERNAL CHRIN
A3D3 [ROM+03D3] C9 0D      CMP #$0D                          
A3D5 [ROM+03D5] F0 22      BEQ L_A3F9                        
A3D7 [ROM+03D7] E0 20      CPX #$20                          
A3D9 [ROM+03D9] D0 F1      BNE L_A3CC                        
A3DB [ROM+03DB] F0 1C      BEQ L_A3F9                        
L_A3DD:
A3DD [ROM+03DD] 8E 00 01   STX $0100                         
A3E0 [ROM+03E0] 20 84 A2   JSR L_A284                        
A3E3 [ROM+03E3] 90 C6      BCC L_A3AB                        
L_A3E5:
A3E5 [ROM+03E5] 9D 10 02   STA $0210,X                       
A3E8 [ROM+03E8] E8         INX                               
A3E9 [ROM+03E9] 20 CF FF   JSR CHRIN                          ; KERNAL CHRIN
A3EC [ROM+03EC] C9 0D      CMP #$0D                          
A3EE [ROM+03EE] F0 09      BEQ L_A3F9                        
A3F0 [ROM+03F0] 20 7D A2   JSR MON_PARSE_HEX_BYTE             ; call/jump to mon parse hex byte
A3F3 [ROM+03F3] 90 B6      BCC L_A3AB                        
A3F5 [ROM+03F5] E0 20      CPX #$20                          
A3F7 [ROM+03F7] D0 EC      BNE L_A3E5                        
L_A3F9:
A3F9 [ROM+03F9] 86 1C      STX $1C                           
A3FB [ROM+03FB] 20 3D A5   JSR MON_PRINT_CR                   ; call/jump to mon print cr
L_A3FE:
A3FE [ROM+03FE] A2 00      LDX #$00                          
A400 [ROM+0400] A0 00      LDY #$00                          
L_A402:
A402 [ROM+0402] B1 C1      LDA ($C1),Y                       
A404 [ROM+0404] DD 10 02   CMP $0210,X                       
A407 [ROM+0407] D0 0C      BNE L_A415                        
A409 [ROM+0409] C8         INY                               
A40A [ROM+040A] E8         INX                               
A40B [ROM+040B] E4 1C      CPX $1C                           
A40D [ROM+040D] D0 F3      BNE L_A402                        
A40F [ROM+040F] 20 36 A2   JSR MON_PRINT_WORD                 ; call/jump to mon print word
A412 [ROM+0412] 20 3A A5   JSR MON_PRINT_SPACE                ; call/jump to mon print space
L_A415:
A415 [ROM+0415] 20 35 A0   JSR MON_INC_PTR                    ; call/jump to mon inc ptr
A418 [ROM+0418] A6 26      LDX $26                           
A41A [ROM+041A] D0 92      BNE L_A3AE                        
A41C [ROM+041C] 20 1F A3   JSR L_A31F                        
A41F [ROM+041F] B0 DD      BCS L_A3FE                        
A421 [ROM+0421] 4C 49 A0   JMP MON_COMMAND_LOOP               ; call/jump to mon command loop
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

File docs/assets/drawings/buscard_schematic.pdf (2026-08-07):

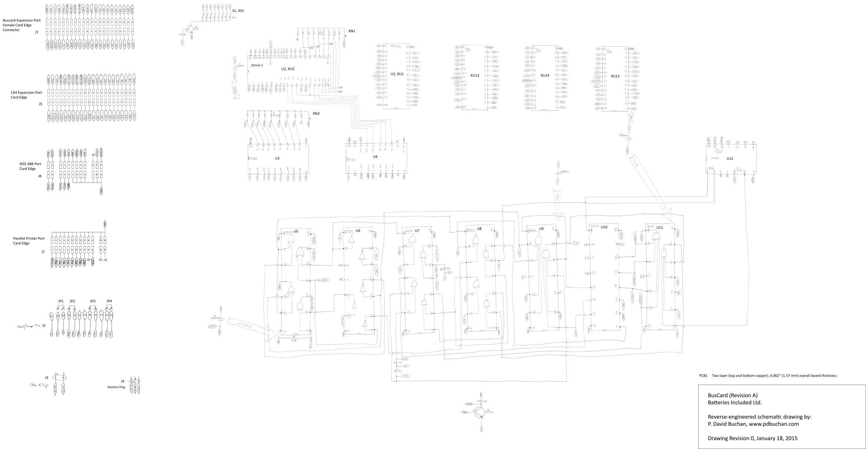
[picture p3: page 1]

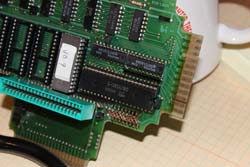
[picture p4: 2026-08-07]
docs/assets/images/diodes_thumb.jpg

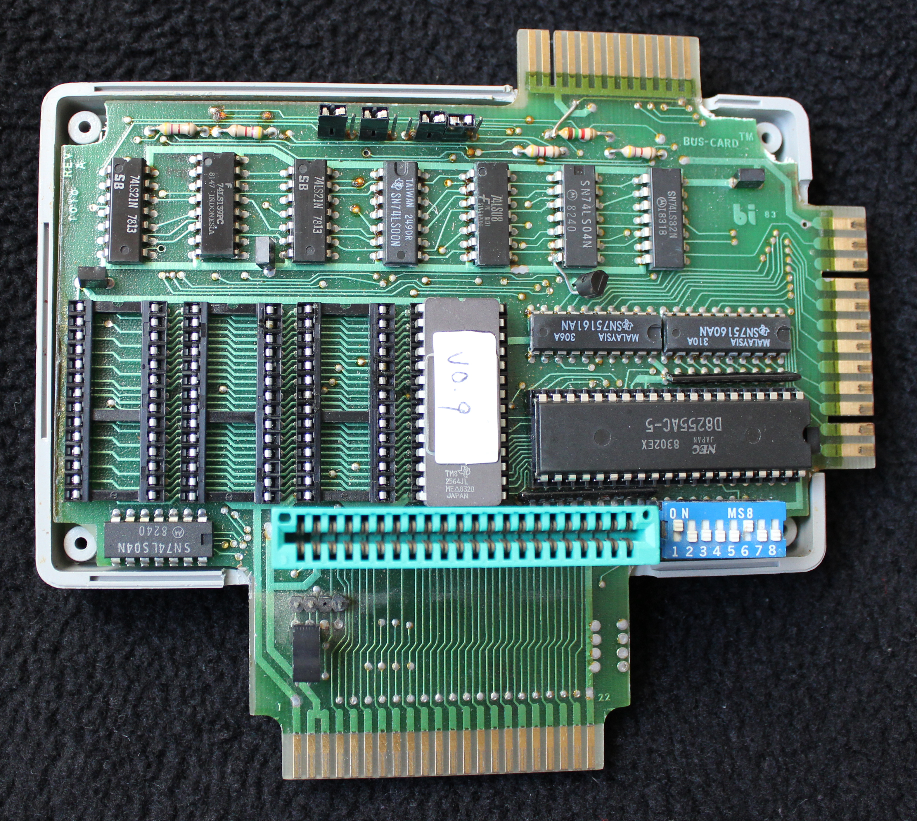
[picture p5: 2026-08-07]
docs/assets/images/top_with_bottom_cover2.jpg

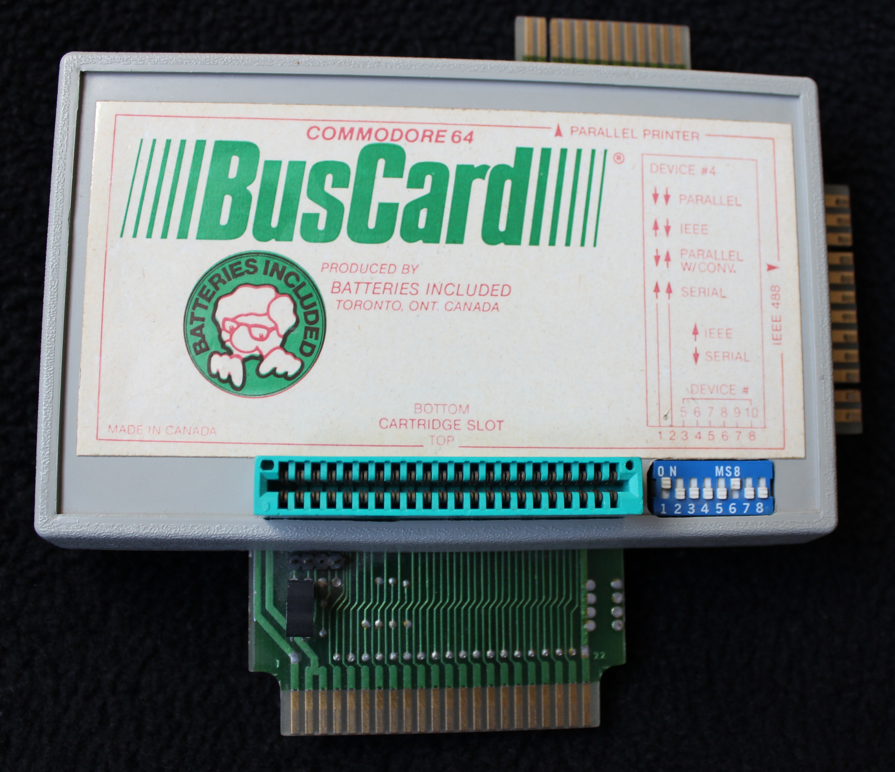
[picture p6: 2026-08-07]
docs/assets/images/top_with_cover2.jpg

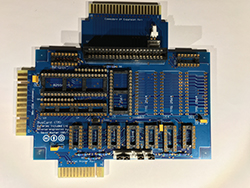
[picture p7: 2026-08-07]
docs/assets/images/new_top_no_chips1_thumb.jpg

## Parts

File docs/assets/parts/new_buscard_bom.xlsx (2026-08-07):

Bill of Materials for Reverse-Engineered BusCard (Revision A)
My Part I.D. | Qty. | Vendor | Vendor I.D. | Technology | Description
Circuit Board | 1 | Elecrow | PCB Prototyping | ENIG | 2-layer, 2-sided, 0.063" (1.6 mm) thick, blue, no stencil, ENIG, card-edges chamfered
U1, U13-15 | 1 | ebay | TMS2564 | TMS 2564 | 65,536-bit, Ultraviolet-Erasable, Electrically Programmable Read-Only Memory (EPROM)
U2 | 1 | Newark | 79K6034 | CP82C55A-5Z | 8-bit Programmable Peripheral Interface, 40-Pin, 5 Mhz
U3 | 1 | Newark | 60K6925 | 75160BN | IEEE-488 GPIB Octal Bus Transceiver
U4 | 1 | Newark | 62K3469 | 75161BN | IEEE-488 GPIB Octal Bus-Management and Data-Transfer Transceiver
U5 | 1 | Newark | 08F7225 | 74LS32N | Quadruple 2-Input Positive-OR Gates
U6, U12 | 2 | Newark | 60K6850 | 74LS04N | Hex Inverting Gates
U7 | 1 | Newark | 60K6852 | 74LS08N | Quadruple 2-Input Positive-AND Gates
U8 | 1 | Newark | 60K6847 | 74LS00N | Quadruple 2-Input Positive-NAND Gates
U9, U11 | 2 | Newark | 08F6993 | 74LS21N | Dual 4-Input Positive-AND Gates
U10 | 1 | Newark | 08F6771 | 74LS139N | Dual 1-of-4 Decoder/Demultiplexer
Q1 | 1 | Newark | 08N8113 | 2N4401 | NPN Transistor, 600 mA, 40 V
Q2 | 1 | Newark | 08N8111 | 2N3904 | NPN Transistor, 200 mA, 40 V
D1-8 | 8 | Newark | 58K9570 | 1N4148 | Small Signal Diode, 200 mA, 100 V
R1, R3, R4-5 | 4 | Newark | 38K0376 | 4.7 kΩ Resistor | Resistor, 4.7 kΩ, 1/4 watt, 5% tolerance
R2 | 1 | Newark | 38K0340 | 1.5 kΩ Resistor | Resistor, 1.5 kΩ, 1/4 watt, 5% tolerance
R6 | 1 | Newark | 38K0327 | 1 kΩ Resistor | Resistor, 1 kΩ, 1/4 watt, 5% tolerance
RN1, RN2 | 2 | Newark | 32K9264 | 4.67 kΩ Resistor Network | SIL Resistor Network, 4.67 kΩ, 10 Pins, 9 Resistors, Bussed Arrangement
C1-4 | 4 | Newark | 87F4662 | CK05BX104K | Ceramic Capacitor, 0.1 μF, 50 V, Radial, 10% tolerance
S1 | 1 | Newark | 40T8914 | 8 SPST DIP Switch | 8 SPST, DIP Switch, Raised Slide
P2 | 1 | Newark | 42K9934 | Female Card-Edge Connector | 44-contact (2-rows of 22 contacts), 0.1" (2.54 mm) contact spacing (pitch), 0.2" (5.08 mm) row spacing, 0.062" (1.57 mm) card thickness, wirewrap termination, 3A, 250 V
XU2 | 1 | Newark | 16M3455 | IC Socket | DIP, 40-Pin (2x20), 0.1" (2.54 mm) contact spacing (pitch), 0.6" (15.24 mm) row spacing
XU1, XU13-15 | 4 | Newark | 52K3643 | IC Socket | DIP, 28-Pin (2x14), 0.1" (2.54 mm) contact spacing (pitch), 0.6" (15.24 mm) row spacing
XU3-4 | 2 | Newark | 17C2233 | IC Socket | DIP, 20-Pin (2x10), 0.1" (2.54 mm) contact spacing (pitch), 0.3" (7.62 mm) row spacing
XU10, XS1 | 2 | Newark | 17C2229 | IC Socket | DIP, 16-Pin (2x8), 0.1" (2.54 mm) contact spacing (pitch), 0.3" (7.62 mm) row spacing
XU5-9, XU11-12 | 7 | Newark | 17C2226 | IC Socket | DIP, 14-Pin (2x7), 0.1" (2.54 mm) contact spacing (pitch), 0.3" (7.62 mm) row spacing
XRN1-2 | 2 | Newark | 52K3253 | SIP Socket for Resistor Network | SIP, 10-Pin (1x10), 0.1" (2.54 mm) contact spacing (pitch)
J2 | 1 | Newark | 90F5641 | 4-position Connector Header | Wire-to-board connector header, 4-position, 1-row, straight, 0.1" (2.54 mm) contact spacing (pitch), MTA-100 series
JP1-4 | 4 | Newark | 90F4251 | 3-position Connector Header | Wire-to-board connector header, 3-position, 1-row, straight, 0.1" (2.54 mm) contact spacing (pitch), MTA-100 series
J1 | 1 | Newark | 90F5638 | 2-position Connector Header | Wire-to-board connector header, 2-position, 1-row, 90-degrees, 0.1" (2.54 mm) contact spacing (pitch), MTA-100 series
Clip Receptacle | 1 | Newark | 52K3585 | 2-position Connector Receptacle | Wire-to-board connector receptacle, 2-position, 1-row, straight, 0.1" (2.54 mm) contact spacing (pitch), MTA-100 series
Clip (red) | 1 | Newark | 13H6565 | Spring-loaded Test Clip | Test Clip, Spring-Loaded, Hook, Red, 3 A, 43.43 mm Overall Length
Clip (black) | 1 | Newark | 48F5003 | Spring-loaded Test Clip | Test Clip, Spring-Loaded, Hook, Black, 3 A, 43.43 mm Overall Length
Clip Cable | 1 | Newark | 67R9277 | Ribbon Cable | Ribbon Cable, Round Conductor, Flat, Zippable, 16 Conductors (peel off 2; you could buy cables with less conductors), 22 AWG, 2.54 mm Spacing
JP1-4 | 4 | Newark | 55H0426 | 2-position Shunt | Shunt, female, 2-position, 0.1" (2.54 mm) contact spacing (pitch), 0.347" (8.81mm) height

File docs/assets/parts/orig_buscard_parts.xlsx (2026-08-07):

Original BusCard (Revision A) Parts List
Part I.D. | Technology | Description
Printed Circuit Board:
PCB1 |  | Two layer (top and bottom copper), 0.062" (1.57 mm) overall board thickness
Integrated Circuits:
U1 | TMS 2564JL | 65,536-bit, Ultraviolet-Erasable, Electrically Programmable Read-Only Memory (EPROM)
U2 | 8255AC-5 | Programmable Peripheral Interface, 40-Pin, 4 MHz
U3 | 75160AN | IEEE-488 GPIB Octal Bus Transceiver
U4 | 75161AN | IEEE-488 GPIB Octal Bus-Management and Data-Transfer Transceiver
U5 | 74LS32N | Quadruple 2-Input Positive-OR Gates
U6 | 74LS04N | Hex Inverting Gates
U7 | 74LS08N | Quadruple 2-Input Positive-AND Gates
U8 | 74LS00N | Quadruple 2-Input Positive-NAND Gates
U9 | 74LS21N | Dual 4-Input Positive-AND Gates
U10 | 74LS139N | Dual 1-of-4 Decoder/Demultiplexer
U11 | 74LS21N | Dual 4-Input Positive-AND Gates
U12 | 74LS04N | Hex Inverting Gates
XU1 |  | IC Socket, DIP, 28-Pin (2x14), 0.1" (2.54 mm) contact spacing (pitch), 0.6" (15.24 mm) row spacing
XU2 |  | IC Socket, DIP, 40-Pin (2x20), 0.1" (2.54 mm) contact spacing (pitch), 0.6" (15.24 mm) row spacing
XU13 |  | IC Socket, DIP, 28-Pin (2x14), 0.1" (2.54 mm) contact spacing (pitch), 0.6" (15.24 mm) row spacing
XU14 |  | IC Socket, DIP, 28-Pin (2x14), 0.1" (2.54 mm) contact spacing (pitch), 0.6" (15.24 mm) row spacing
XU15 |  | IC Socket, DIP, 28-Pin (2x14), 0.1" (2.54 mm) contact spacing (pitch), 0.6" (15.24 mm) row spacing
Transistors:
Q1 | 2N4401 | NPN Transistor, 600 mA, 40 V
Q2 | 2N3904 | NPN Transistor, 200 mA, 40 V
Diodes:
D1 | 1N4148 | Small Signal Diode, 200 mA, 100 V
D2 | 1N4148 | Small Signal Diode, 200 mA, 100 V
D3 | 1N4148 | Small Signal Diode, 200 mA, 100 V
D4 | 1N4148 | Small Signal Diode, 200 mA, 100 V
D5 | 1N4148 | Small Signal Diode, 200 mA, 100 V
D6 | 1N4148 | Small Signal Diode, 200 mA, 100 V
D7 | 1N4148 | Small Signal Diode, 200 mA, 100 V
D8 | 1N4148 | Small Signal Diode, 200 mA, 100 V
Resistors:
R1 |  | 4.7 kΩ, 1/4 watt, 5% tolerance
R2 |  | 1.5 kΩ, 1/4 watt, 5% tolerance
R3 |  | 4.7 kΩ, 1/4 watt, 5% tolerance
R4 |  | 4.7 kΩ, 1/4 watt, 5% tolerance
R5 |  | 4.7 kΩ, 1/4 watt, 5% tolerance
R6 |  | 1 kΩ, 1/4 watt, 5% tolerance
RN1 |  | SIL Resistor Network, 4.67 kΩ, 10 Pins, 9 Resistors, Bussed Arrangement
RN2 |  | SIL Resistor Network, 4.67 kΩ, 10 Pins, 9 Resistors, Bussed Arrangement
Capacitors:
C1 | CK05BX104K | Ceramic Capacitor, 0.1 μF, 50 V, Radial, 10% tolerance
C2 | CK05BX104K | Ceramic Capacitor, 0.1 μF, 50 V, Radial, 10% tolerance
C3 | CK05BX104K | Ceramic Capacitor, 0.1 μF, 50 V, Radial, 10% tolerance
C4 | CK05BX104K | Ceramic Capacitor, 0.1 μF, 50 V, Radial, 10% tolerance
Switch:
S1 |  | 8 SPST, DIP Switch, Raised Slide
XS1 |  | IC Socket, DIP, 16-Pin (2x8), Wirewrap, 0.1" (2.54 mm) contact spacing (pitch), 0.3" (7.62 mm) row spacing
Jacks and Plugs:
J1 |  | Female Card Edge Connector, EDAC 345-044-540-201, 44-contact (2-rows of 22 contacts), 0.1" (2.54 mm) contact spacing (pitch), 0.2" (5.08 mm) row spacing, 0.062" (1.57 mm) card thickness, wirewrap termination, 3A, 250 V
J2 |  | Jumper pins consisting of 12 wirewrap pins used in conjunction with JP1-4. These can be grouped by function into four groups of three pins. i.e., there are three pins available, and therefore two possible positions, for each of the four 2-position shunts (JP1, 2, 3, and 4).
J3 |  | Consists of 2 wirewrap pins
J4 |  | Consists of 3 pins (a 4-pin header with a gap where one pin was removed)
J5 |  | 0.1" (2.54 mm) contact spacing (pitch), 0.2" (5.08 mm) row spacing
J6 |  | 0.156" (3.96 mm) contact spacing (pitch), 0.2" (5.08 mm) row spacing
J7 |  | 0.1" (2.54 mm) contact spacing (pitch), 0.2" (5.08 mm) row spacing
JP1 |  | Shunt, 2-Position
JP2 |  | Shunt, 2-Position
JP3 |  | Shunt, 2-Position
JP4 |  | Shunt, 2-Position

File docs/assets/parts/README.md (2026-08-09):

# Parts list for reverse-engineered BusCard

| File | Description |
|---|---|
| `new_buscard_bom.xlsx` | Parts list of new BusCard as Microsoft Excel spreadsheet |
| `orig_buscard_parts.xlsx` | Parts list of original BusCard as Microsoft Excel spreadsheet |

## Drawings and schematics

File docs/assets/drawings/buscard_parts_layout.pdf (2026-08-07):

J5

U12 J1

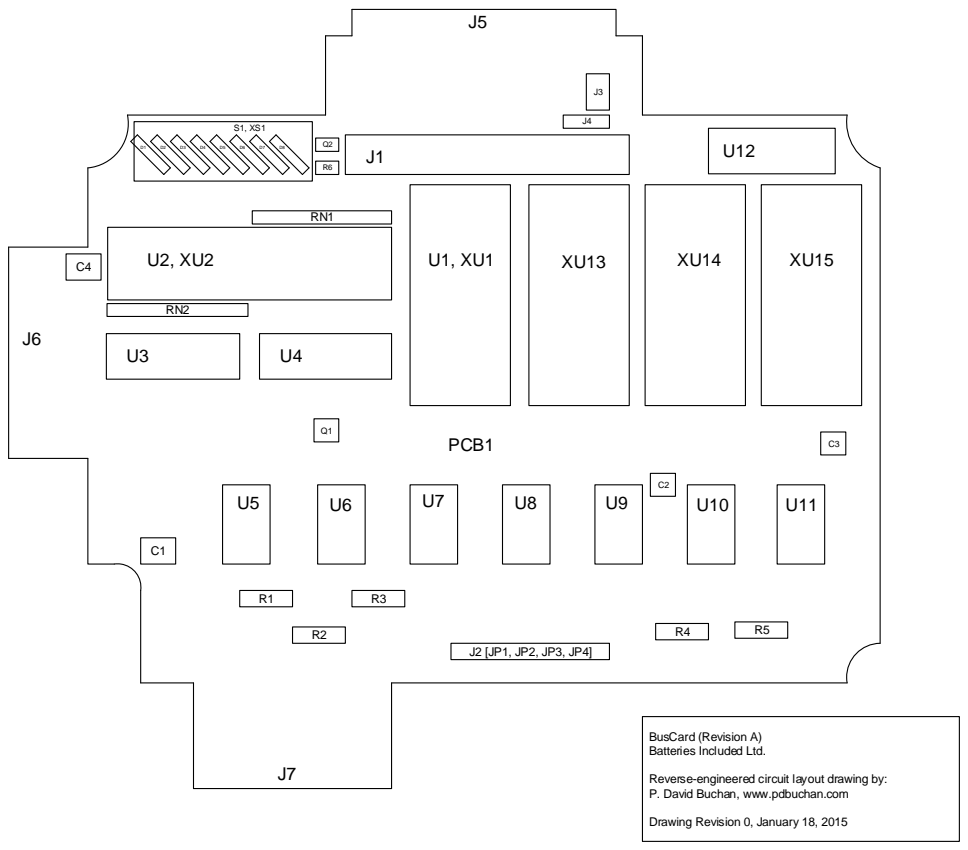
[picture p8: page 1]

Reverse-engineered circuit layout drawing by:
P. David Buchan, www.pdbuchan.com

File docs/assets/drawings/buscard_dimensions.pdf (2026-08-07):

J5

8

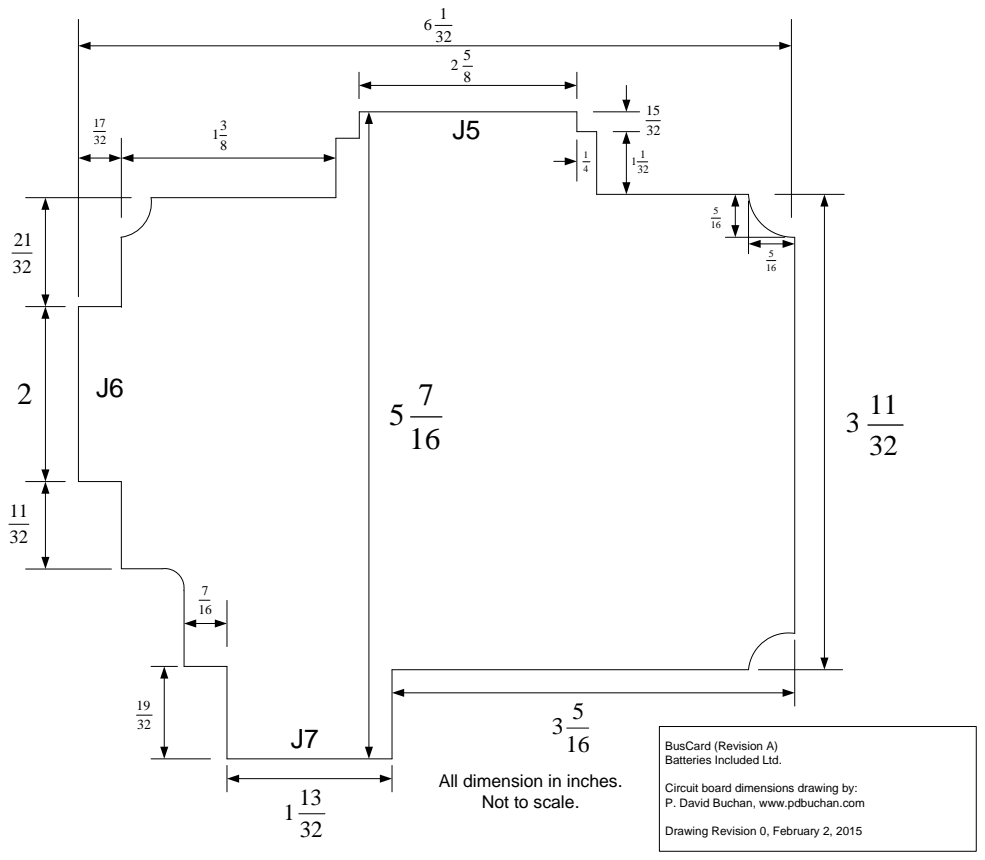
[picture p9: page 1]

BusCard (Revision A)
Batteries Included Ltd. Circuit board dimensions drawing by: P. David Buchan, www.pdbuchan.com Drawing Revision 0, February 2, 2015

All dimension in inches. Not to scale. 32

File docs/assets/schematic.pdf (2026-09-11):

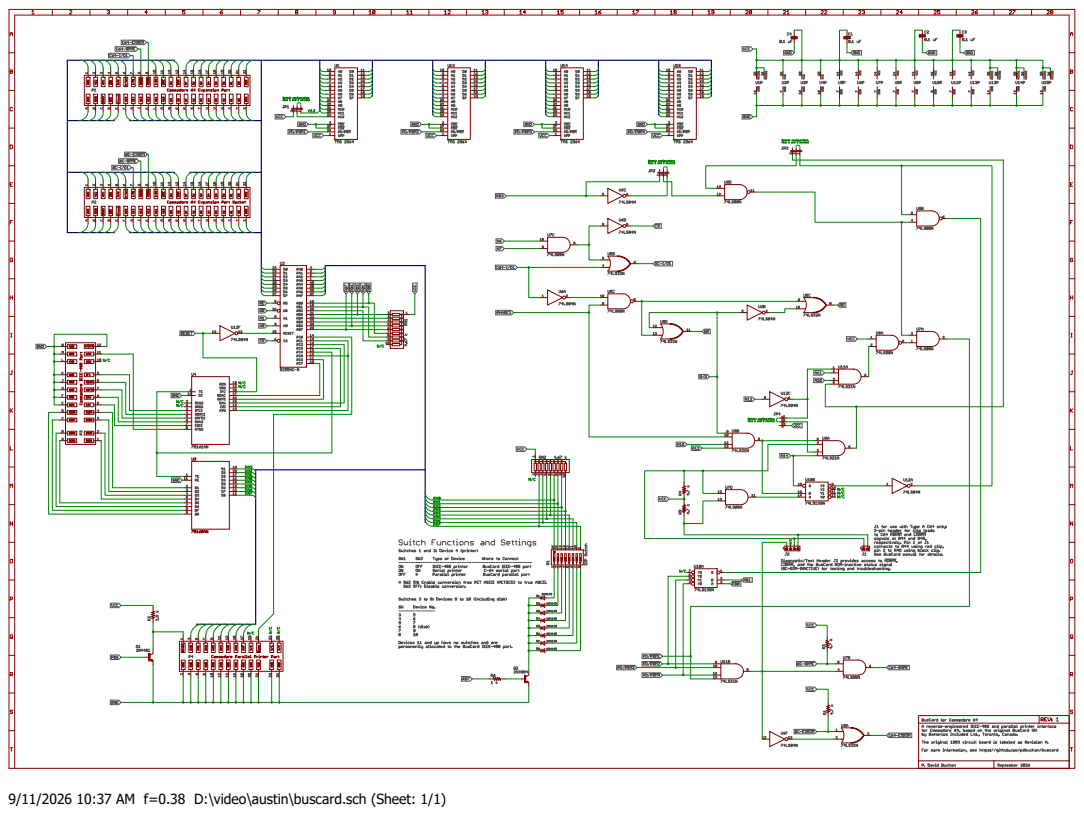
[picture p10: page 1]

9/11/2026 10:37 AM f=0.38 D:\video\austin\buscard.sch (Sheet: 1/1)

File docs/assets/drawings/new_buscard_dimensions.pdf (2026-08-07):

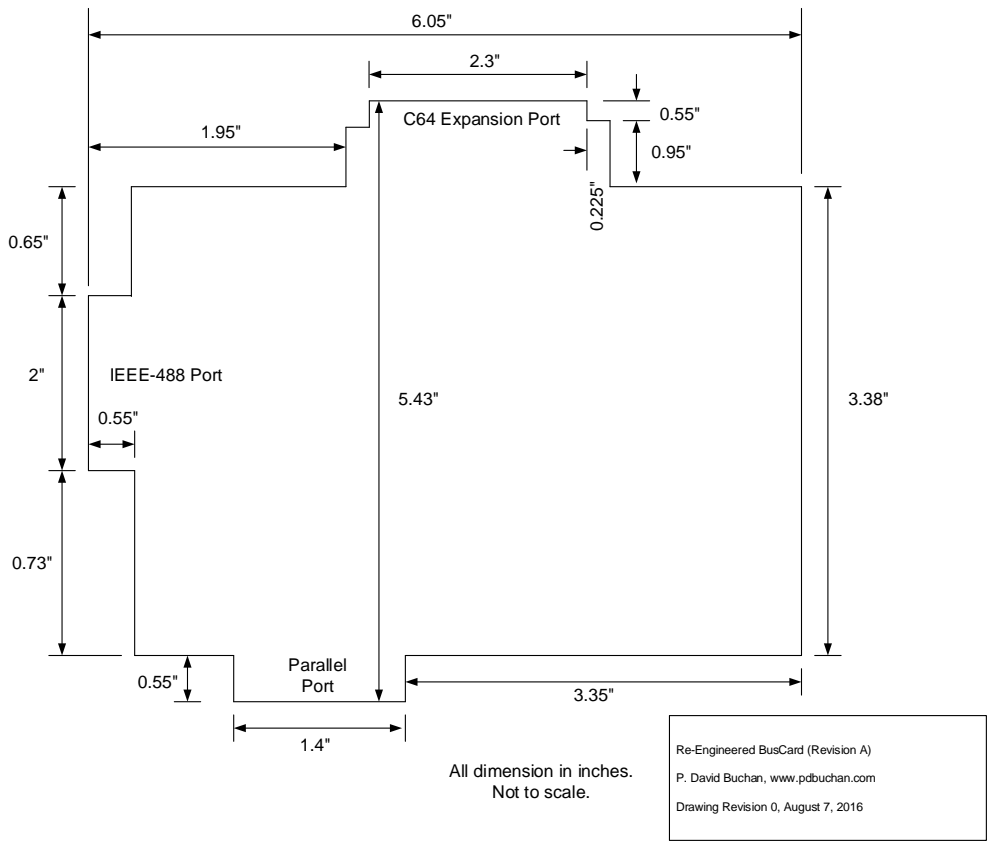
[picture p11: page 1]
C64 Expansion Port; IEEE-488 Port; Parallel Port

Re-Engineered BusCard (Revision A)

All dimension in inches.
Not to scale.

P. David Buchan, www.pdbuchan.com

Drawing Revision 0, August 7, 2016

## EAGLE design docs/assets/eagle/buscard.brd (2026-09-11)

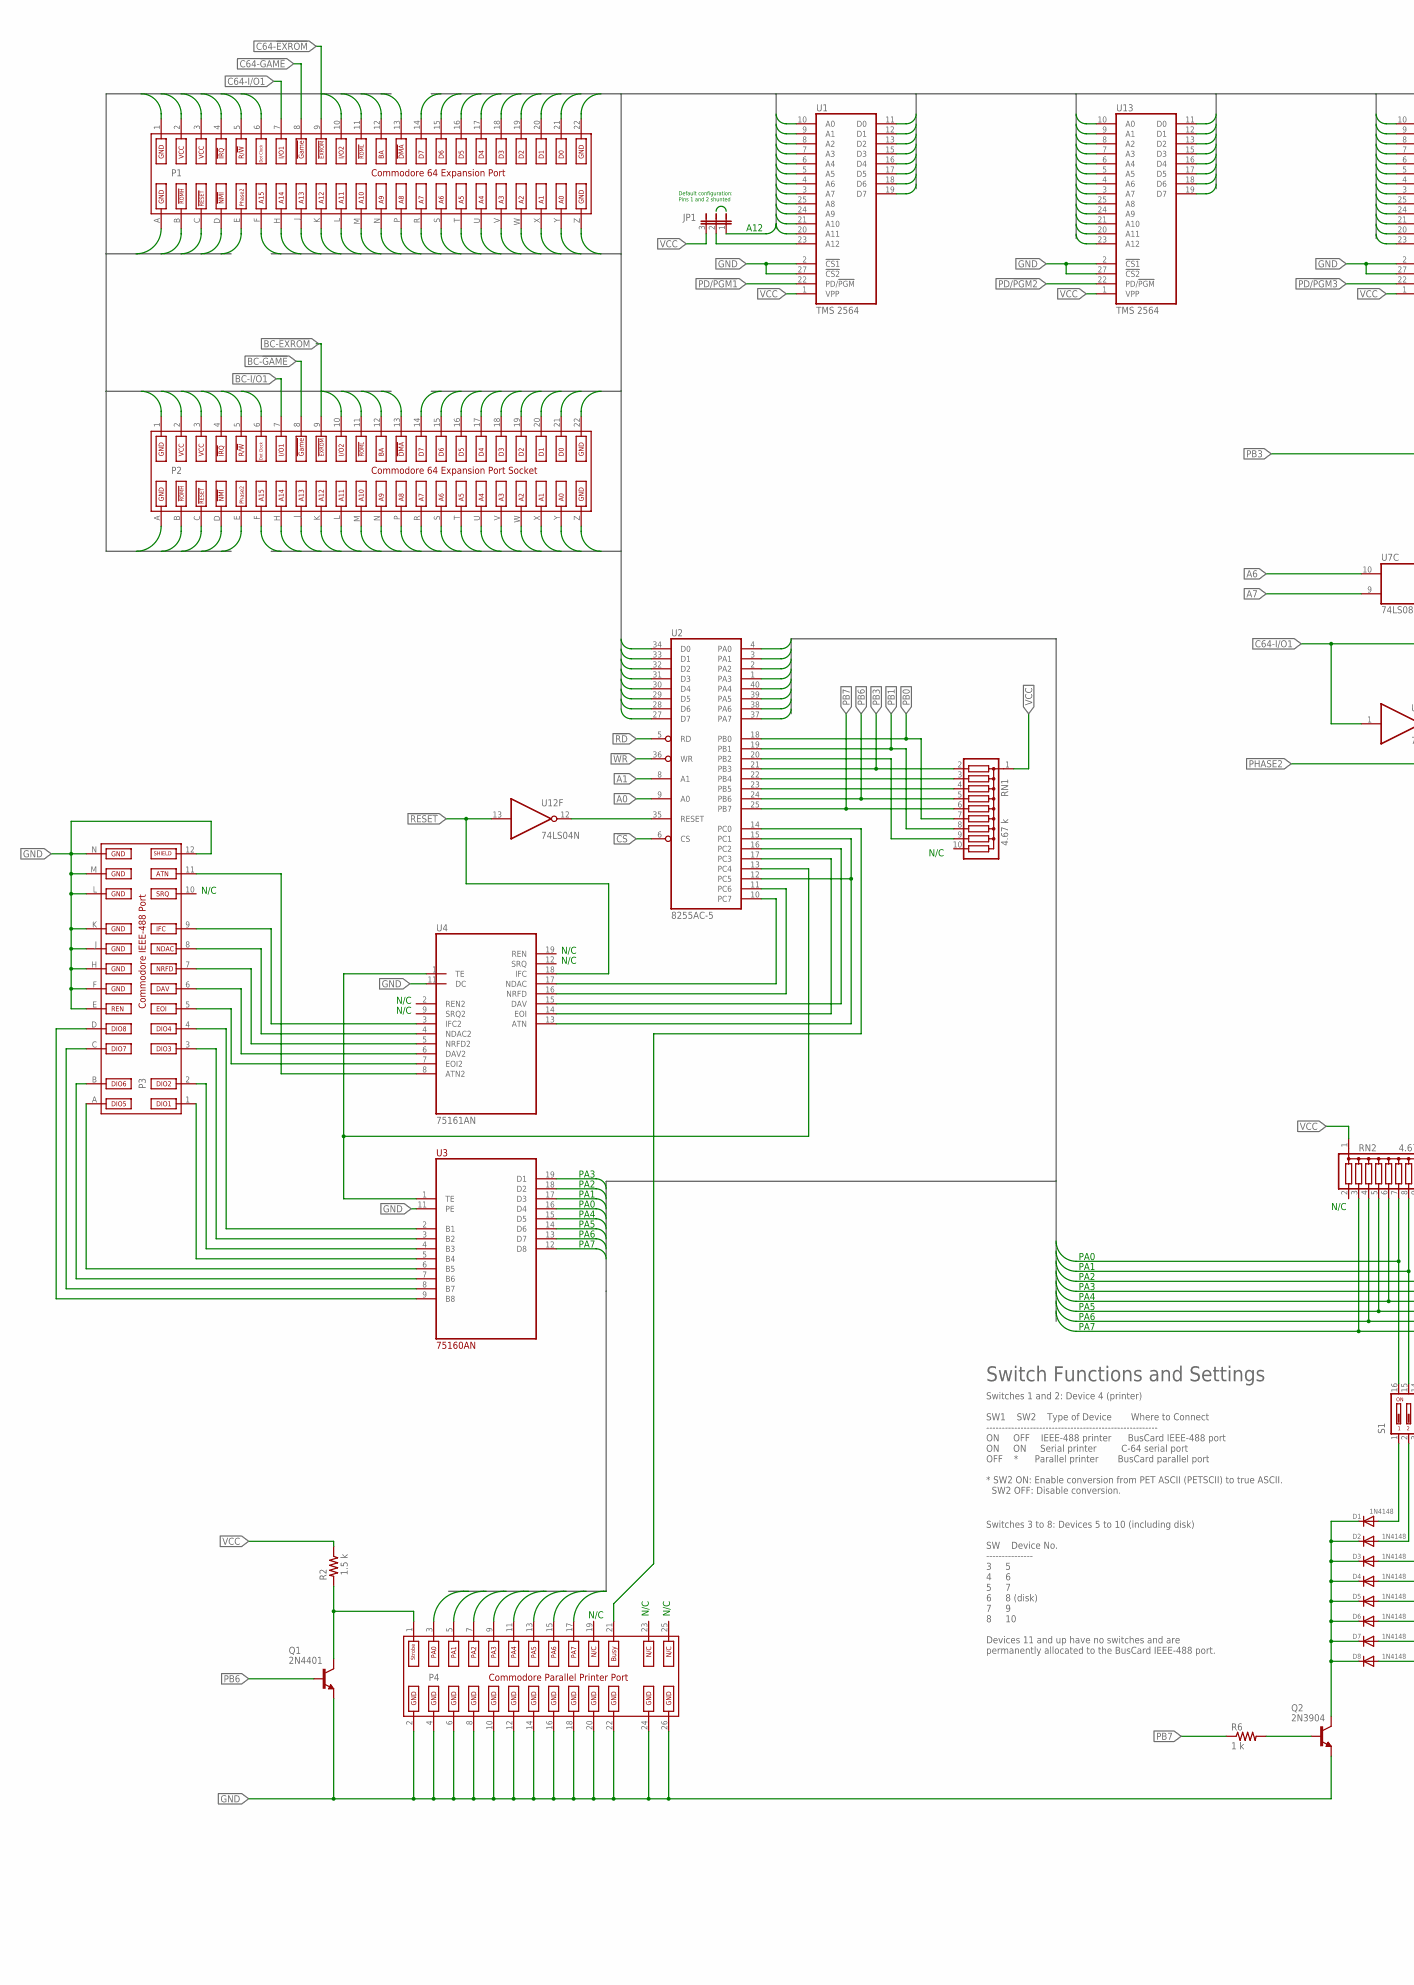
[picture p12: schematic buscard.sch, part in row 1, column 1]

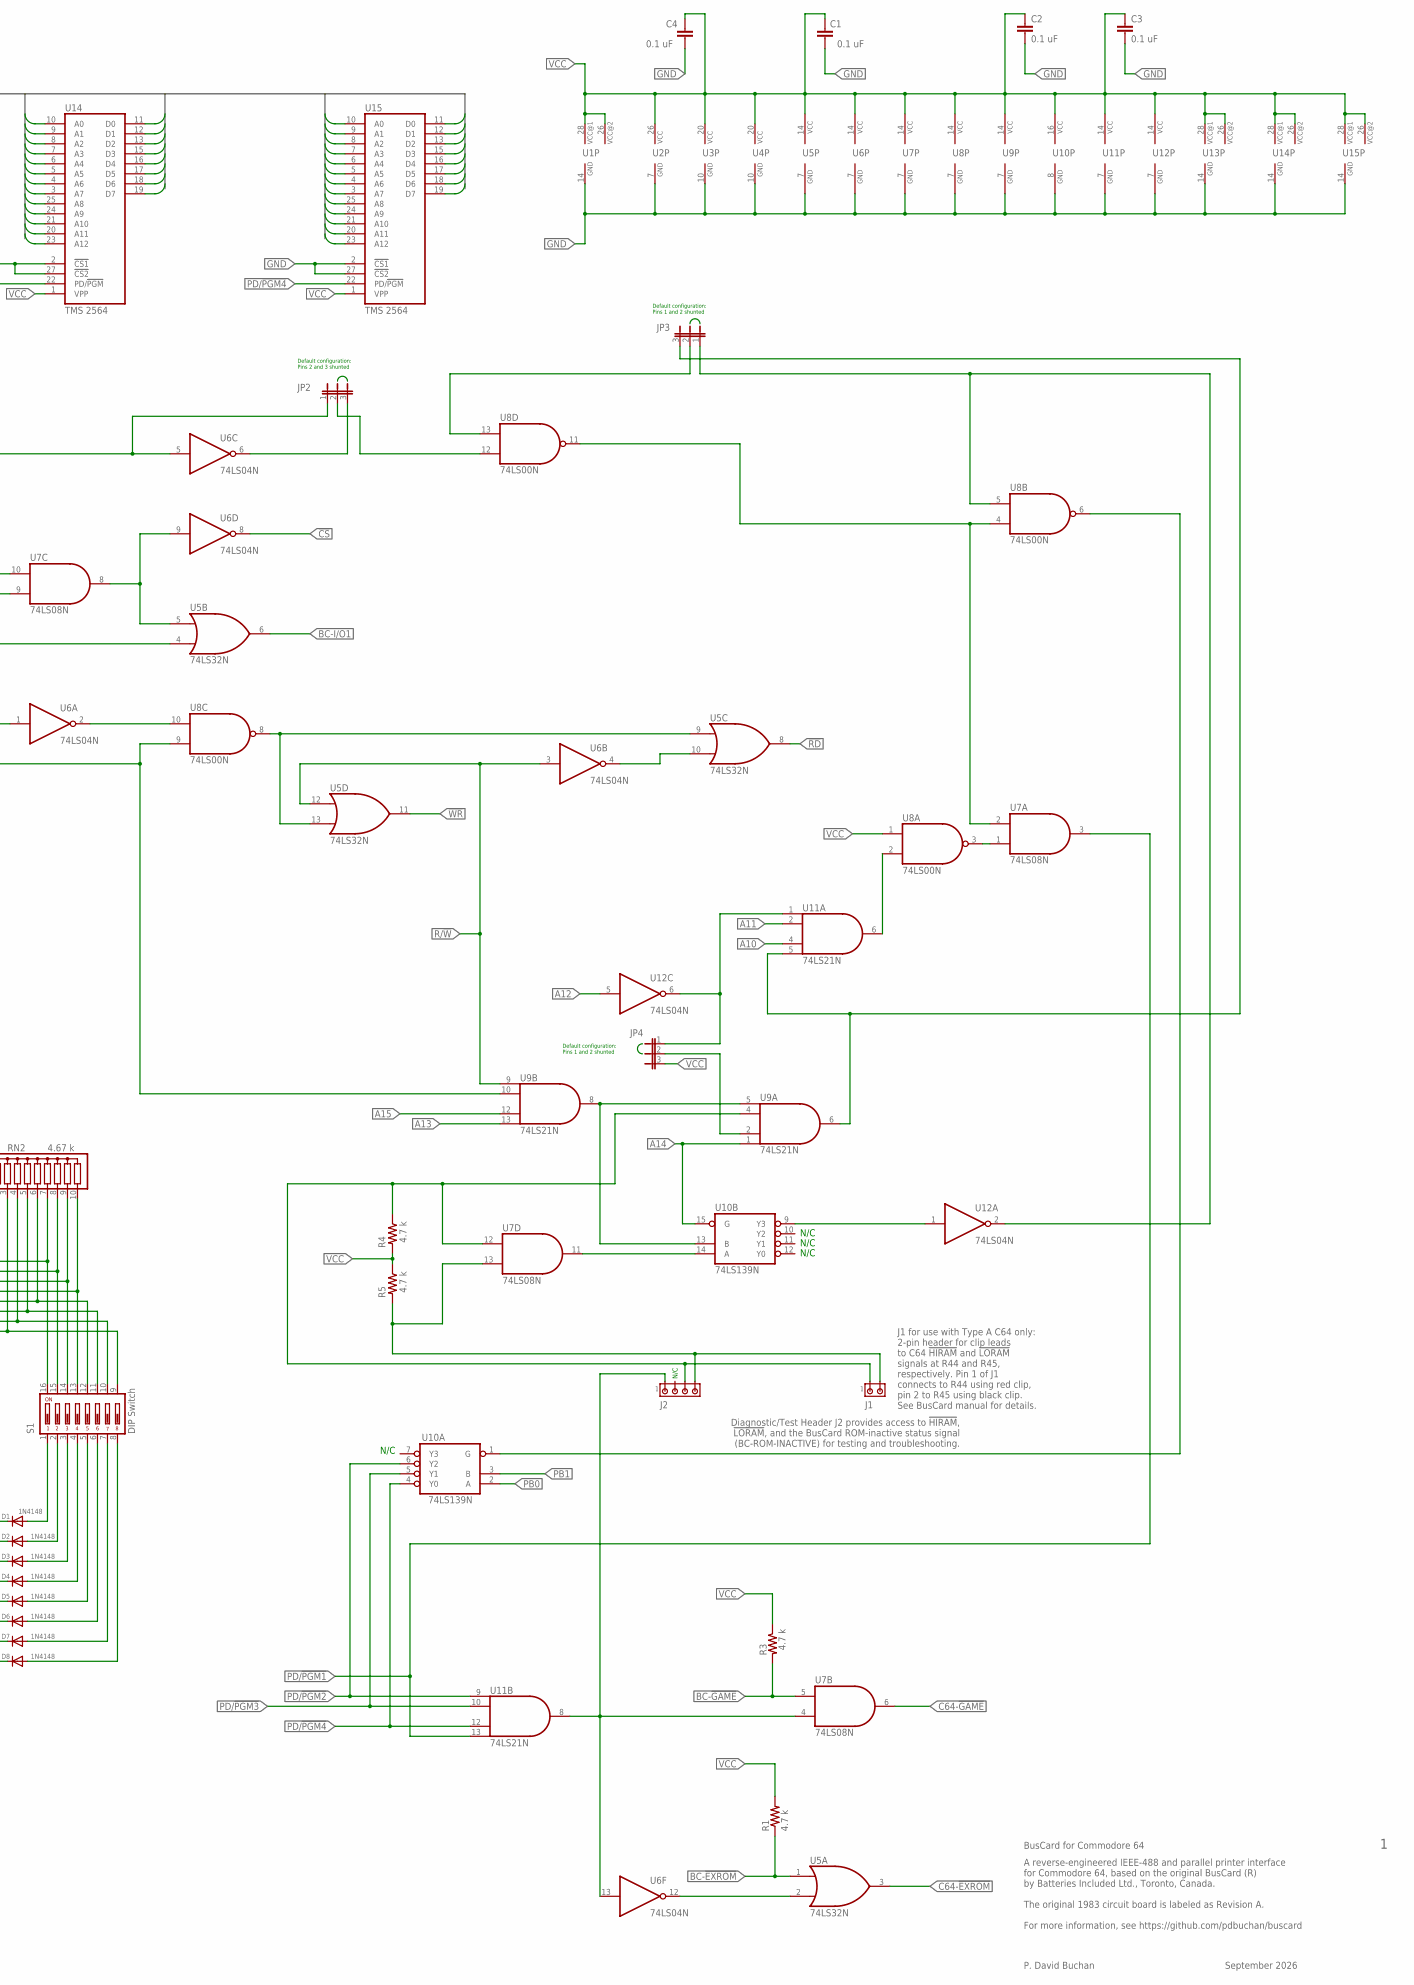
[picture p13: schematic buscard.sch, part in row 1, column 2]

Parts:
C1, C2, C3, C4: 0.1 uF; C075-032X103
D1, D2, D3, D4, D5, D6, D7, D8: 1N4148; DO-1N4148-0.2
J1: MTA02-100; 10X02MTA
J2: MTA04-100; 10X04MTA
JP1, JP2, JP3, JP4: JUMPER-HEADER-3-POSMTA-100; JUMPER-HEADER-3-POS
P1: COMMODORE_64_EXPANSION_PORT_CARD_EDGE
P2: FEMALE_44-PIN_CARD_EDGE_CONNECTOR
P3: COMMODORE_IEEE-488_PORT_CARD_EDGE
P4: Parallel Port; COMMODORE_PARALLEL_PORT_CARD_EDGE
Q1: 2N4401; TO92-EBC
Q2: 2N3904; TO92
R1, R3, R4, R5: 4.7 k; 0207/10
R2: 1.5 k; 0207/10
R6: 1 k; 0207/10
RN1, RN2: 4.67 k; SIL10
S1: DIP Switch; DS-08
U1, U13, U14, U15: TMS 2564; DIL28
U2: 8255AC-5; DIL40
U3: 75160AN; DIL20
U4: 75161AN; DIL20
U5: 74LS32N; DIL14
U6, U12: 74LS04N; DIL14
U7: 74LS08N; DIL14
U8: 74LS00N; DIL14
U9, U11: 74LS21N; DIL14
U10: 74LS139N; DIL16

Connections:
!CS: U2.6 (CS), U6.8 (O)
!DMA: P1.13 (!DMA), P2.13 (!DMA)
!IRQ: P1.4 (!IRQ), P2.4 (!IRQ)
!NMI: P1.D (!NMI), P2.D (!NMI)
!RD: U2.5 (RD), U5.8 (O)
!RESET: P1.C (!RESET), P2.C (!RESET), U4.18 (IFC), U12.13 (I)
!ROMH: P1.B (!ROMH), P2.B (!ROMH)
!ROML: P1.11 (!ROML), P2.11 (!ROML)
!WR: U2.36 (WR), U5.11 (O)
A0: P1.Y (A0), P2.Y (A0), U1.10 (A0), U2.9 (A0), U13.10 (A0), U14.10 (A0), U15.10 (A0)
A1: P1.X (A1), P2.X (A1), U1.9 (A1), U2.8 (A1), U13.9 (A1), U14.9 (A1), U15.9 (A1)
A2: P1.W (A2), P2.W (A2), U1.8 (A2), U13.8 (A2), U14.8 (A2), U15.8 (A2)
A3: P1.V (A3), P2.V (A3), U1.7 (A3), U13.7 (A3), U14.7 (A3), U15.7 (A3)
A4: P1.U (A4), P2.U (A4), U1.6 (A4), U13.6 (A4), U14.6 (A4), U15.6 (A4)
A5: P1.T (A5), P2.T (A5), U1.5 (A5), U13.5 (A5), U14.5 (A5), U15.5 (A5)
A6: P1.S (A6), P2.S (A6), U1.4 (A6), U7.10 (I1), U13.4 (A6), U14.4 (A6), U15.4 (A6)
A7: P1.R (A7), P2.R (A7), U1.3 (A7), U7.9 (I0), U13.3 (A7), U14.3 (A7), U15.3 (A7)
A8: P1.P (A8), P2.P (A8), U1.25 (A8), U13.25 (A8), U14.25 (A8), U15.25 (A8)
A9: P1.N (A9), P2.N (A9), U1.24 (A9), U13.24 (A9), U14.24 (A9), U15.24 (A9)
A10: P1.M (A10), P2.M (A10), U1.21 (A10), U11.4 (I2), U13.21 (A10), U14.21 (A10), U15.21 (A10)
A11: P1.L (A11), P2.L (A11), U1.20 (A11), U11.2 (I1), U13.20 (A11), U14.20 (A11), U15.20 (A11)
A12: JP1.1, P1.K (A12), P2.K (A12), U12.5 (I), U13.23 (A12), U14.23 (A12), U15.23 (A12)
A13: P1.J (A13), P2.J (A13), U9.13 (I3)
A14: P1.H (A14), P2.H (A14), U9.1 (I0), U10.15 (G)
A15: P1.F (A15), P2.F (A15), U9.12 (I2)
ATN: P3.11 (ATN), U4.8 (ATN2)
BA: P1.12 (BA), P2.12 (BA)
BC-!EXROM: P2.9 (!EXROM), R1.1, U5.1 (I0)
BC-!GAME: P2.8 (!GAME), R3.2, U7.5 (I1)
BC-I/O1: P2.7 (I/O1), U5.6 (O)
BC-ROM-INACTIVE: J2.1, U6.13 (I), U7.4 (I0), U11.8 (O)
BUSY: P4.21 (BUSY), U2.14 (PC0)
C64-!EXROM: P1.9 (!EXROM), U5.3 (O)
C64-!GAME: P1.8 (!GAME), U7.6 (O)
C64-I/O1: P1.7 (I/O1), U5.4 (I0), U6.1 (I)
CLIP1: J1.2, J2.4, R5.2, U7.13 (I1)
CLIP2: J1.1, J2.3, R4.1, U7.12 (I0), U9.4 (I2)
D0: P1.21 (D0), P2.21 (D0), U1.11 (D0), U2.34 (D0), U13.11 (D0), U14.11 (D0), U15.11 (D0)
D1: P1.20 (D1), P2.20 (D1), U1.12 (D1), U2.33 (D1), U13.12 (D1), U14.12 (D1), U15.12 (D1)
D2: P1.19 (D2), P2.19 (D2), U1.13 (D2), U2.32 (D2), U13.13 (D2), U14.13 (D2), U15.13 (D2)
D3: P1.18 (D3), P2.18 (D3), U1.15 (D3), U2.31 (D3), U13.15 (D3), U14.15 (D3), U15.15 (D3)
D4: P1.17 (D4), P2.17 (D4), U1.16 (D4), U2.30 (D4), U13.16 (D4), U14.16 (D4), U15.16 (D4)
D5: P1.16 (D5), P2.16 (D5), U1.17 (D5), U2.29 (D5), U13.17 (D5), U14.17 (D5), U15.17 (D5)
D6: P1.15 (D6), P2.15 (D6), U1.18 (D6), U2.28 (D6), U13.18 (D6), U14.18 (D6), U15.18 (D6)
D7: P1.14 (D7), P2.14 (D7), U1.19 (D7), U2.27 (D7), U13.19 (D7), U14.19 (D7), U15.19 (D7)
DAV: P3.6 (DAV), U4.6 (DAV2)
DIO1: P3.1 (DIO1), U3.5 (B4)
DIO2: P3.2 (DIO2), U3.4 (B3)
DIO3: P3.3 (DIO3), U3.3 (B2)
DIO4: P3.4 (DIO4), U3.2 (B1)
DIO5: P3.A (DIO5), U3.6 (B5)
DIO6: P3.B (DIO6), U3.7 (B6)
DIO7: P3.C (DIO7), U3.8 (B7)
DIO8: P3.D (DIO8), U3.9 (B8)
DOT_CLOCK: P1.6 (DOT_CLOCK), P2.6 (DOT_CLOCK)
EOI: P3.5 (EOI), U4.7 (EOI2)
GND: C1.1, C2.2, C3.2, C4.2, P1.1 (GND), P1.22 (GND), P1.A (GND), P1.Z (GND), P2.1 (GND), P2.22 (GND), P2.A (GND), P2.Z (GND), P3.12 (SHIELD), P3.E (REN), P3.F (GND), P3.H (GND), P3.J (GND), P3.K (GND), P3.L (GND), P3.M (GND), P3.N (GND), P4.2 (GND), P4.4 (GND), P4.6 (GND), P4.8 (GND), P4.10 (GND), P4.12 (GND), P4.14 (GND), P4.16 (GND), P4.18 (GND), P4.20 (GND), P4.22 (GND), P4.24 (GND), P4.26 (GND), Q1.E, Q2.3 (E), U1.2 (!CS1), U1.14 (GND), U1.27 (!CS2), U2.7 (GND), U3.10 (GND), U3.11 (PE), U4.10 (GND), U4.11 (DC), U5.7 (GND), U6.7 (GND), U7.7 (GND), U8.7 (GND), U9.7 (GND), U10.8 (GND), U11.7 (GND), U12.7 (GND), U13.2 (!CS1), U13.14 (GND), U13.27 (!CS2), U14.2 (!CS1), U14.14 (GND), U14.27 (!CS2), U15.2 (!CS1), U15.14 (GND), U15.27 (!CS2)
I/O2: P1.10 (I/O2), P2.10 (I/O2)
IFC: P3.9 (IFC), U4.3 (IFC2)
unnamed: JP2.3, U6.6 (O)
unnamed: JP2.2, U8.12 (I0)
unnamed: JP3.2, U8.13 (I1)
unnamed: U8.6 (O), U10.1 (G)
unnamed: U6.2 (O), U8.10 (I1)
unnamed: U5.10 (I1), U6.4 (O)
unnamed: U5.9 (I0), U5.13 (I1), U8.8 (O)
unnamed: U9.5 (I3), U9.8 (O), U10.13 (B)
unnamed: U8.2 (I1), U11.6 (O)
unnamed: JP4.2, U9.2 (I1)
unnamed: JP4.1, U11.1 (I0), U12.6 (O)
unnamed: JP3.3, U9.6 (O), U11.5 (I3)
unnamed: U7.1 (I0), U8.3 (O)
unnamed: U10.9 (Y3), U12.1 (I)
unnamed: U7.11 (O), U10.14 (A)
unnamed: D1.A, S1.1
unnamed: U5.2 (I1), U6.12 (O)
unnamed: D2.A, S1.2
unnamed: D3.A, S1.3
unnamed: D4.A, S1.4
unnamed: D5.A, S1.5
unnamed: D6.A, S1.6
unnamed: D7.A, S1.7
unnamed: JP1.2, U1.23 (A12)
unnamed: D8.A, S1.8
unnamed: U2.10 (PC7), U4.17 (NDAC)
unnamed: Q2.2 (B), R6.2
unnamed: D1.C, D2.C, D3.C, D4.C, D5.C, D6.C, D7.C, D8.C, Q2.1 (C)
unnamed: U2.11 (PC6), U4.16 (NRFD)
unnamed: RN1.3, U2.22 (PB4)
unnamed: RN1.4, U2.23 (PB5)
unnamed: RN1.9, U2.20 (PB2)
unnamed: U2.16 (PC2), U4.15 (DAV)
unnamed: U2.35 (RESET), U12.12 (O)
unnamed: U7.2 (I1), U8.4 (I0), U8.11 (O)
unnamed: JP3.1, U8.5 (I1), U12.2 (O)
unnamed: U5.5 (I1), U6.9 (I), U7.8 (O)
unnamed: U2.17 (PC3), U4.14 (EOI)
unnamed: U2.12 (PC5), U2.15 (PC1), U4.13 (ATN)
NDAC: P3.8 (NDAC), U4.4 (NDAC2)
NRFD: P3.7 (NRFD), U4.5 (NRFD2)
PA0: P4.3 (PA0), RN2.7, S1.16, U2.4 (PA0), U3.16 (D4)
PA1: P4.5 (PA1), RN2.8, S1.15, U2.3 (PA1), U3.17 (D3)
PA2: P4.7 (PA2), RN2.9, S1.14, U2.2 (PA2), U3.18 (D2)
PA3: P4.9 (PA3), RN2.10, S1.13, U2.1 (PA3), U3.19 (D1)
PA4: P4.11 (PA4), RN2.6, S1.12, U2.40 (PA4), U3.15 (D5)
PA5: P4.13 (PA5), RN2.5, S1.11, U2.39 (PA5), U3.14 (D6)
PA6: P4.15 (PA6), RN2.4, S1.10, U2.38 (PA6), U3.13 (D7)
PA7: P4.17 (PA7), RN2.3, S1.9, U2.37 (PA7), U3.12 (D8)
PB0: RN1.7, U2.18 (PB0), U10.2 (A)
PB1: RN1.8, U2.19 (PB1), U10.3 (B)
PB3: JP2.1, RN1.2, U2.21 (PB3), U6.5 (I)
PB6: Q1.B, RN1.5, U2.24 (PB6)
PB7: R6.1, RN1.6, U2.25 (PB7)
PD/!PGM1: U1.22 (PD/!PGM), U7.3 (O), U11.13 (I3)
PD/!PGM2: U10.6 (Y2), U11.9 (I0), U13.22 (PD/!PGM)
PD/!PGM3: U10.5 (Y1), U11.10 (I1), U14.22 (PD/!PGM)
PD/!PGM4: U10.4 (Y0), U11.12 (I2), U15.22 (PD/!PGM)
PHASE2: P1.E (PHASE2), P2.E (PHASE2), U8.9 (I0), U9.10 (I1)
R/!W: P1.5 (R/!W), P2.5 (R/!W), U5.12 (I0), U6.3 (I), U9.9 (I0)
STROBE: P4.1 (STROBE), Q1.C, R2.2
TE: U2.13 (PC4), U3.1 (TE), U4.1 (TE)
VCC: C1.2, C2.1, C3.1, C4.1, JP1.3, JP4.3, P1.2 (VCC), P1.3 (VCC), P2.2 (VCC), P2.3 (VCC), R1.2, R2.1, R3.1, R4.2, R5.1, RN1.1, RN2.1, U1.1 (VPP), U1.26 (VCC), U1.28 (VCC), U2.26 (VCC), U3.20 (VCC), U4.20 (VCC), U5.14 (VCC), U6.14 (VCC), U7.14 (VCC), U8.1 (I0), U8.14 (VCC), U9.14 (VCC), U10.16 (VCC), U11.14 (VCC), U12.14 (VCC), U13.1 (VPP), U13.26 (VCC), U13.28 (VCC), U14.1 (VPP), U14.26 (VCC), U14.28 (VCC), U15.1 (VPP), U15.26 (VCC), U15.28 (VCC)

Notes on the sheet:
N/C
PA3
PA2
PA1
PA0
PA4
PA5
PA6
PA7
P. David Buchan
BusCard for Commodore 64
A reverse-engineered IEEE-488 and parallel printer interface for Commodore 64, based on the original BusCard (R) by Batteries Included Ltd., Toronto, Canada. The original 1983 circuit board is labeled as Revision A. For more information, see https://github.com/pdbuchan/buscard
Diagnostic/Test Header J2 provides access to !HIRAM!, !LORAM!, and the BusCard ROM-inactive status signal (BC-ROM-INACTIVE) for testing and troubleshooting.
September 2026
Switch Functions and Settings
Switches 1 and 2: Device 4 (printer) SW1 SW2 Type of Device Where to Connect ------------------------------------------------------- ON OFF IEEE-488 printer BusCard IEEE-488 port ON ON Serial printer C-64 serial port OFF * Parallel printer BusCard parallel port * SW2 ON: Enable conversion from PET 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
Switches 3 to 8: Devices 5 to 10 (including disk) SW Device No. --------------- 3 5 4 6 5 7 6 8 (disk) 7 9 8 10 Devices 11 and up have no switches and are permanently allocated to the BusCard IEEE-488 port.
J1 for use with Type A C64 only: 2-pin header for clip leads to C64 !HIRAM! and !LORAM! signals at R44 and R45, respectively. Pin 1 of J1 connects to R44 using red clip, pin 2 to R45 using black clip. See BusCard manual for details.
A12
Default configuration: Pins 1 and 2 shunted
Default configuration: Pins 2 and 3 shunted

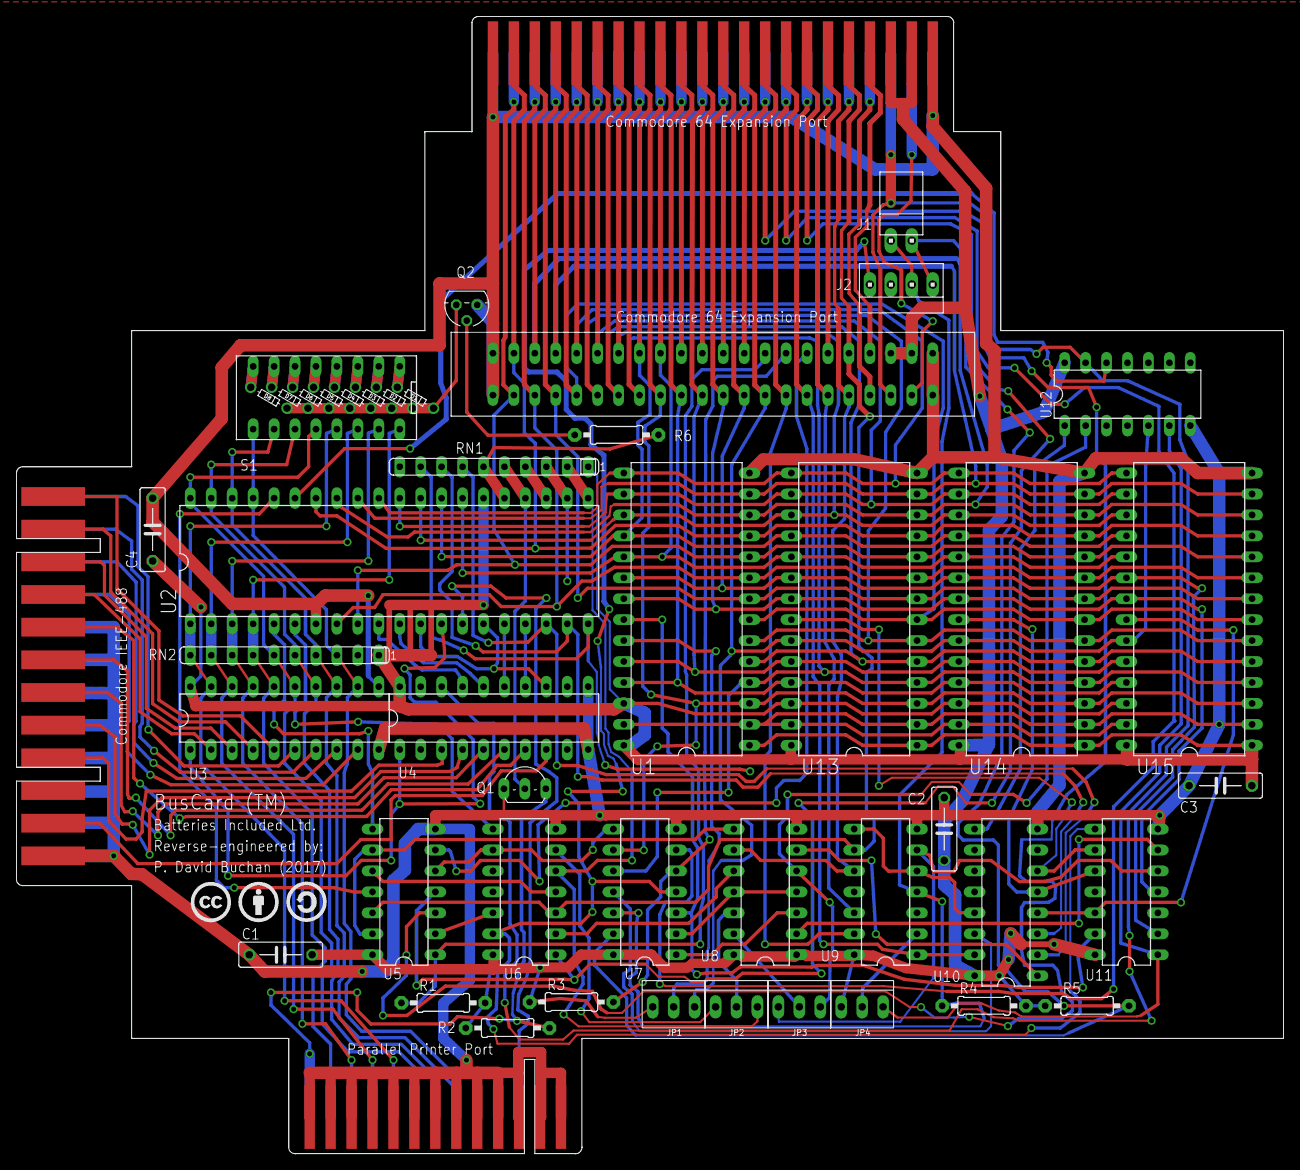
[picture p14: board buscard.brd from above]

Board: 2 copper layers, 153.7 x 137.9 mm, 48 parts (0 on the bottom side), 122 nets.

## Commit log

2026-08-08 Added discussion of U13, U14, and U15 EPROM sockets
2026-09-11 Clarified diagnostic header info
    [buscard.brd, buscard.sch]
